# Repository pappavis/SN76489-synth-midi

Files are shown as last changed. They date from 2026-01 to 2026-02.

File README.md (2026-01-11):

Educatieve DIY USB-MIDI synthesizer gebaseerd op de SN76489 PSG,
aangestuurd via een ESP32-C2 met CircuitPython en een PCF8574
(I2C → parallel).

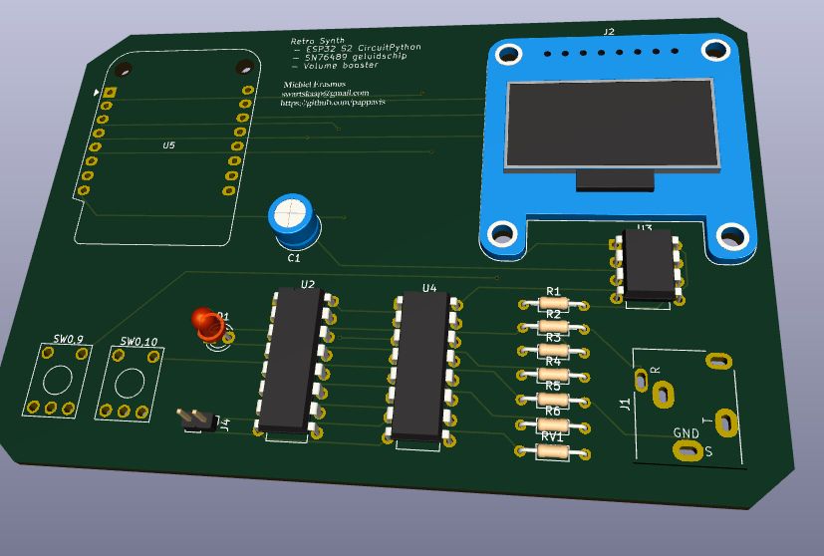
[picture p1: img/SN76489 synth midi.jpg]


# Functionele specificaties  

## Ontwerpfilosofie
- Eerst breadboard, dan PCB
- Alles meetbaar met scope en multimeter
- Geen SMD-componenten
- Focus op leerbaarheid en reproduceerbaarheid

## Signaalpad (verplicht)
ESP32-C2 (USB MIDI)
→ PCF8574
→ SN76489
→ analoge filtering
→ variabel mono volume
→ audio-versterker
→ 3.5 mm TRS koptelefoon (dual-mono)

## Projectstatus
- [x] Stap 1 – Functionele specificaties
- [ ] Stap 2 – Technische specificaties
- [ ] Stap 3 – Blokdiagram
- [ ] Stap 4 – Breadboard ontwerp
- [ ] Stap 5 – Audio-versterker evaluatie
- [ ] Stap 6 – KiCad schema & PCB
- [ ] Stap 7 – Firmware architectuur
- [ ] Stap 8 – Test & debug
- [ ] Stap 9 – Verbeteringen

➡️ Begin bij `docs/01-functional-spec.md`
sn76489-midi-synth/
├── README.md
├── docs/
│   ├── 01-functional-spec.md
│   ├── 02-technical-spec.md
│   ├── 03-block-diagram.md
│   ├── 04-breadboard-design.md
│   ├── 05-audio-options-evaluation.md
│   ├── 06-kicad-design.md
│   ├── 07-firmware-architecture.md
│   ├── 08-test-and-debug.md
│   └── 09-improvements-and-next-steps.md
├── hardware/
│   ├── breadboard/
│   └── pcb/
├── firmware/
│   ├── circuitpython/
│   └── tools/
└── media/
    ├── photos/
    └── scope-captures/

# Werk-in-uitvoering

## Functioneel schema
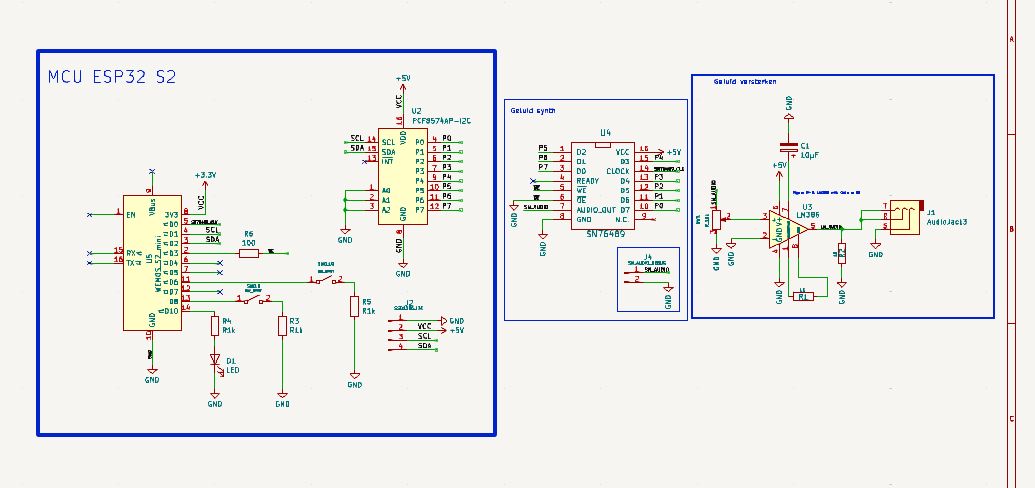
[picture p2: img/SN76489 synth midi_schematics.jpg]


## Printplaat klaar voor China-produtie
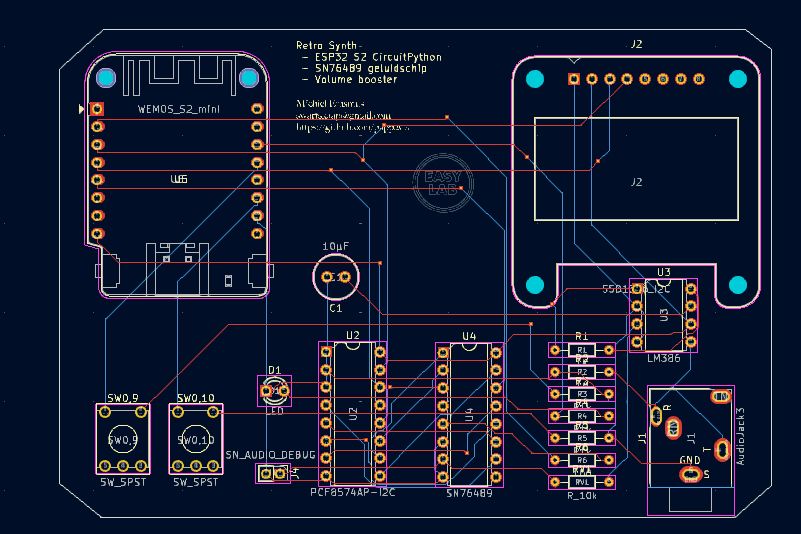
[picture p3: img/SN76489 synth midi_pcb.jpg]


# CREDITS
In een opwelling gemaakt op een koude Zaterdagmiddag.

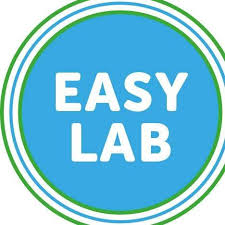
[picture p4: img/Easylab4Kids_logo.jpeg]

Michiel Erasmus

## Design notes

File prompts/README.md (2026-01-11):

9-Jan-2026. Help mij om een prompt te schrijven als hobby-elektronica-ontwikkelaar vergelijkbaar met iemand zoals Krijtskot op YouTube.

# idee
Ik wil een SN76489IC chip gebruiken met een ESP32C2 om daar een MIDI synth van te maken. De ESP32-C2 wordt door Logic Pro gezien als Midi controller.  De ESP32 vertaalt midi noten naar  Sn76489 
De ESP32 C2 midi controller "firmware" wordt ontwikkeld met CircuitPython.

# instructies
1. Genereer een  prompt die mij helpen van functionele specificaties maken, naar technische specs, naar KICAD schema ontwerp, en de juiste . Jouw output in Markdown formaat waar nodig.
2. Blijf verbeter voorstellen doen totdat ik zeg je moet stop.
3. Verwerk de instructies van deze prompt in jouw reactie.

# Informatiebronnen
1. zie mijn eigen KiCAD PCB ontwerp op https://github.com/pappavis/EasyLab-retro-synth-SN76489
2. SN76489 datasheet --> https://map.grauw.nl/resources/sound/texas_instruments_sn76489an.pdf

Blijf verbetervoorstellen doen zodat ik deze prompt kan verbeteren

toevoegen aan de voorbeeld prompt:

=====
Je bent een ervaren hobby-elektronica ontwikkelaar en educator, in de stijl van GreatScott op YouTube:
pragmatisch, technisch eerlijk, nieuwsgierig en iteratief.

## Projectcontext
Ik bouw een DIY MIDI-synth op basis van de SN76489 sound chip en een ESP32-C2.
- De ESP32-C2 draait CircuitPython
- De ESP32-C2 wordt door Logic Pro herkend als USB MIDI device
- MIDI Note On/Off, velocity en channel worden vertaald naar SN76489 register writes
 - Geluid output van de SN76489 is naar een TENSATR PCM5102 Interface I2S DAC Decoder  (https://nl.aliexpress.com/item/1005009897846559.html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)
- Doel: leerzaam, reproduceerbaar en uitbreidbaar ontwerp

## Informatiebronnen
- Bestaand KiCad project: https://github.com/pappavis/EasyLab-retro-synth-SN76489
- SN76489 datasheet: https://map.grauw.nl/resources/sound/texas_instruments_sn76489an.pdf

## Taken (voer deze in volgorde uit)
1. Formuleer functionele specificaties (gebruikersniveau)
2. Vertaal deze naar technische specificaties (signalen, timing, spanningen)
3. Ontwerp een logisch blokdiagram (tekstueel beschreven)
4. Werk toe naar een KiCad-schema:
   - voedingsontwerp
   - klokbron
   - data- en controlijnen SN76489
   - ESP32-C2 pinmapping
5. Beschrijf firmware-architectuur in CircuitPython:
   - MIDI stack
   - notenmapping
   - timingstrategie
6. Benoem risico’s, onzekerheden en meetpunten
7. Doe concrete verbetervoorstellen en stel expliciet vervolgvragen

## Extra aandachtspunten
- Ga uit van SN76489AN compatibiliteit en benoem verschillen met SN76496
- Houd rekening met write-timing (minimum pulse widths)
- Veronderstel geen interrupts in CircuitPython zonder dit expliciet te motiveren
- Beschrijf hoe je het ontwerp zou testen met een logic analyzer en scope
- Geef alternatieven als CircuitPython timing tekortschiet

## Educatieve insteek
- Leg beslissingen uit alsof dit een YouTube-episode is
- Benoem expliciet: "dit is waarom dit fout kan gaan"
- Splits het project in afleveringen / milestones
- Benoem wat je NIET doet en waarom
- Geef suggesties voor toekomstige uitbreidingen:
  - envelope generator
  - noise channel modulation
  - polyfonie via multiple SN chips

## Stijl
- Markdown waar nuttig
- Geen marketingtaal
- Leg keuzes uit alsof je ze op camera verdedigt
- Doe altijd verbetervoorstellen tot ik "stop" zeg

# Mijn Update aan jouw concept prompt .

Ik wil de SN76489 geluid output volume kunnen boosten door bijvoorbeeld de PCM5102 module  te vervangen met een LM386, de geluid output moet op kanaal links en rechts zijn. De output geluid met een variable volume naar een koptelefoon TRS-output.
Update de prompt 
# met voorstel voor alternatieven van een LM386.
# De chip ontwerp is ESP32 C2 als midicontroller --> PCF8574 I2c --> SN76489 --> variabel (mono) volume zoals potmeter --> volume booster module/breakoutboard  --> TRS output
# toevoegen aan jouw voorstel prompt.
de test en ontwerp software en apparatuur tot mijn beschikking:
 - Kicad 8.0
 - 3d printer
 - Riden RC6006 labvoeding
 - RIGOL DHO804 oscilloscoop
 - Aneng SZ02 multimeter
 - Breadbords
 - Jumper kabels
 - verschillende microcontrollers zoals Pi PICO, ESp32 S2, ESP32 C3.

 update aan de prompt.
1. Stap 1 is beginnen met een KICAD ontwerp ESP32 --> PC8574 --> SN76489 --> LM386 --> dual mono booster zoals een SAM-breakoutboard --> variabel volume beheer bijvb door een potmeter --> TRS headphone audio out jack.
2. De ontwerp heeft ook een SSD1302 I2C mini LCD voor gebruikers output.

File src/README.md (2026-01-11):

# CircuitPython Skeleton (SN76489 + PCF8574)

# Instructies
Hier is je minimale CircuitPython skeleton als ZIP (main.py + drivers + config + diagnostics):

Download sn76489_circuitpython_skeleton.zip￼

Gebruik (kort):
	1.	Unzip.
	2.	Kopieer de inhoud naar je CIRCUITPY drive.
	3.	Zet in system/config.py je PCF_ADDR en (indien nodig) PCF_STROBE_BIT.
	4.	Start met TEST_MODE = "pcf_counter" (scope op D0..D7 + strobe).
	5.	Daarna TEST_MODE = "sn_beep" (scope op strobe + audio out).

## Wat is dit?
Minimale bring-up firmware voor:
- I2C scan (MP1)
- PCF8574 data togglen (MP2)
- SN76489 byte writes + simpele beep (MP3/MP4)
- OLED status (optioneel; faalt veilig)

## Installatie (CircuitPython)
1. Flash CircuitPython op je ESP32-C2 board.
2. Kopieer de hele inhoud van deze map naar de CIRCUITPY drive.
3. Installeer (optioneel) OLED libs als je het display gebruikt:
   - adafruit_ssd1306.mpy
   - adafruit_display_text/
   - terminalio (meestal ingebouwd)

## Test modes
In `system/config.py`:
- `TEST_MODE = "pcf_counter"`  → PCF bus telt 0..255 (scope op D0..D7)
- `TEST_MODE = "sn_beep"`      → SN76489 korte beep
- `TEST_MODE = None`           → idle loop

## Belangrijk
- Dit skeleton bevat nog geen USB-MIDI parser.
- Eerst hardware brengen naar "beep" en "stabiele bus". Daarna MIDI laag toevoegen.

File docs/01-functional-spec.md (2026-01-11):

# Stap 1 – Functionele specificaties
DIY USB-MIDI PSG-synth (SN76489 + ESP32-C2)

## 1. Hoofdfunctie
Een standalone USB-MIDI synthesizer die MIDI-noten omzet naar
klassieke PSG-audio via de SN76489, met regelbare mono-audio
op een koptelefoonuitgang.

## 2. Gebruikersperspectief
### Input
- USB MIDI device
- Note On / Off
- Velocity (optioneel)
- MIDI Channel

### Output
- Direct hoorbaar geluid
- Fysieke volumeregeling
- 3.5 mm TRS koptelefoon (dual-mono)

### Feedback
- OLED-display (SSD1306/1309-klasse)
- Toon van MIDI-status en actieve voices

## 3. Synth-gedrag
- 3 toonkanalen + 1 noise-kanaal
- Monofonisch per kanaal
- Geen envelopes of modulatie

## 4. Digitale keten
USB MIDI
→ ESP32-C2 (CircuitPython)
→ PCF8574
→ SN76489
→ analoge audio

## 5. Audio-pad
SN76489
→ filtering
→ volumepotmeter
→ audio-versterker
→ koptelefoon

## 6. Buiten scope
Geen presets, geen CC’s, geen stereo, geen batterij,
geen SMD, geen PCB-optimalisatie.

## 7. Meetbaarheid
Alles moet testbaar zijn op breadboard met scope,
multimeter en serial debug.

## 8. Succescriteria
Heldere scope, reproduceerbaar ontwerp,
en een solide basis voor stap 2.

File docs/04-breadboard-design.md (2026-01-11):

- Dit punt ligt **bij de voeding / USB-entry**
- Audio-ground mag **nooit** via ESP32 of I2C teruglopen

---

## 3. Digitale sectie – wiring details

### 3.1 ESP32-C2

- Voeding: via USB
- Gebruik alleen:
  - SDA
  - SCL
  - 1–2 GPIO’s voor SN76489 control (via PCF)
- Geen lange jumper wires (>10 cm = fout)

### 3.2 I2C-bus

- SDA + SCL getwist of parallel naast elkaar
- Pull-ups: 4.7–10 kΩ naar **+5 V_DIG**
- Devices:
  - PCF8574
  - OLED

Testregel:
- Eerst I2C scan → dan pas SN76489 aansluiten

---

## 4. PCF8574 → SN76489 wiring

### 4.1 Parallel data

- PCF8574 D0–D7 → SN76489 data bus
- Draden:
  - zo kort mogelijk
  - naast elkaar (geen kruisende audio)

### 4.2 Control lines

- WE / strobe apart en zichtbaar routen
- Label op breadboard (tape!) aanbevolen

Meetpunt MP2 / MP3:
- Je moet hier met de scope **duidelijk pulsen** zien

---

## 5. Audio sectie – wiring details (Optie B leidend)

### 5.1 SN76489 audio out

- AC-koppeling **direct bij SN76489**
- Daarna pas draad richting potmeter

Fout:
- Eerst lange draad → dan C_in (pikt rommel op)

### 5.2 Potmeter

- Mono, 10–50 kΩ log
- Aansluiting:
  - boven: audio in
  - midden: wiper → versterker
  - onder: GND_AUD

### 5.3 Opamp-versterker (Optie B)

- Zo dicht mogelijk opgebouwd
- Decoupling:
  - 100 nF direct tussen VCC en GND
  - Cref (47–100 µF) bij Vref-node
- Vref-buffer fysiek dichtbij opamp

### 5.4 TRS jack

- Tip = L
- Ring = R
- Sleeve = GND_AUD
- Serie-R en C_out **vlakbij jack**

---

## 6. Absolute breadboard no-go’s

- ❌ Audio en I2C draden door elkaar
- ❌ GND-lussen
- ❌ Lange ongefilterde audio-ingang
- ❌ Geen decoupling “omdat het ook zonder werkt”
- ❌ Alles op één rail “want dat is makkelijker”

---

## 7. Bouwvolgorde (afdwingend)

### Fase 1 – Digitaal leven
1. ESP32 → USB
2. USB MIDI zichtbaar
3. OLED werkt
4. I2C scan ziet PCF8574

### Fase 2 – Parallel output
5. PCF8574 outputs togglen (LED of scope)
6. Strobe-lijn zichtbaar op scope

### Fase 3 – PSG
7. SN76489 aangesloten
8. Eenvoudige “beep” via vaste waarde
9. Audio zichtbaar op scope (MP4)

### Fase 4 – Audio pad
10. Potmeter werkt (MP5)
11. Opamp versterkt correct
12. Koptelefoon-uitgang schoon (MP6)

**Niet doorbouwen als een eerdere fase niet klopt.**

---

## 8. Meetplan (samenvatting MP0–MP6)

| Meetpunt | Wat | Verwachting |
|---|-----|---|
| MP0 | USB MIDI | Device zichtbaar |
| MP1 | I2C scan | OLED + PCF ACK |
| MP2 | PCF data | Bits togglen |
| MP3 | Strobe | Duidelijke pulses |
| MP4 | PSG audio | Klein AC signaal |
| MP5 | Potmeter | Variërende amplitude |
| MP6 | Jack L/R | Identiek signaal |

---

## 9. Succescriteria Stap 4

Stap 4 is geslaagd als:
- Breadboard visueel logisch is
- Elk blok apart meetbaar is
- Ruis en fouten **herleidbaar** zijn
- Je zonder schema kunt uitleggen wat waar gebeurt

---

## Volgende stap
**Stap 5 – Audio-opties evaluatie (A/B/C)**  
→ Optie A en B zijn nu uitgewerkt  
→ Optie C kan nog toegevoegd worden  
→ Daarna: definitieve keuze voor PCB

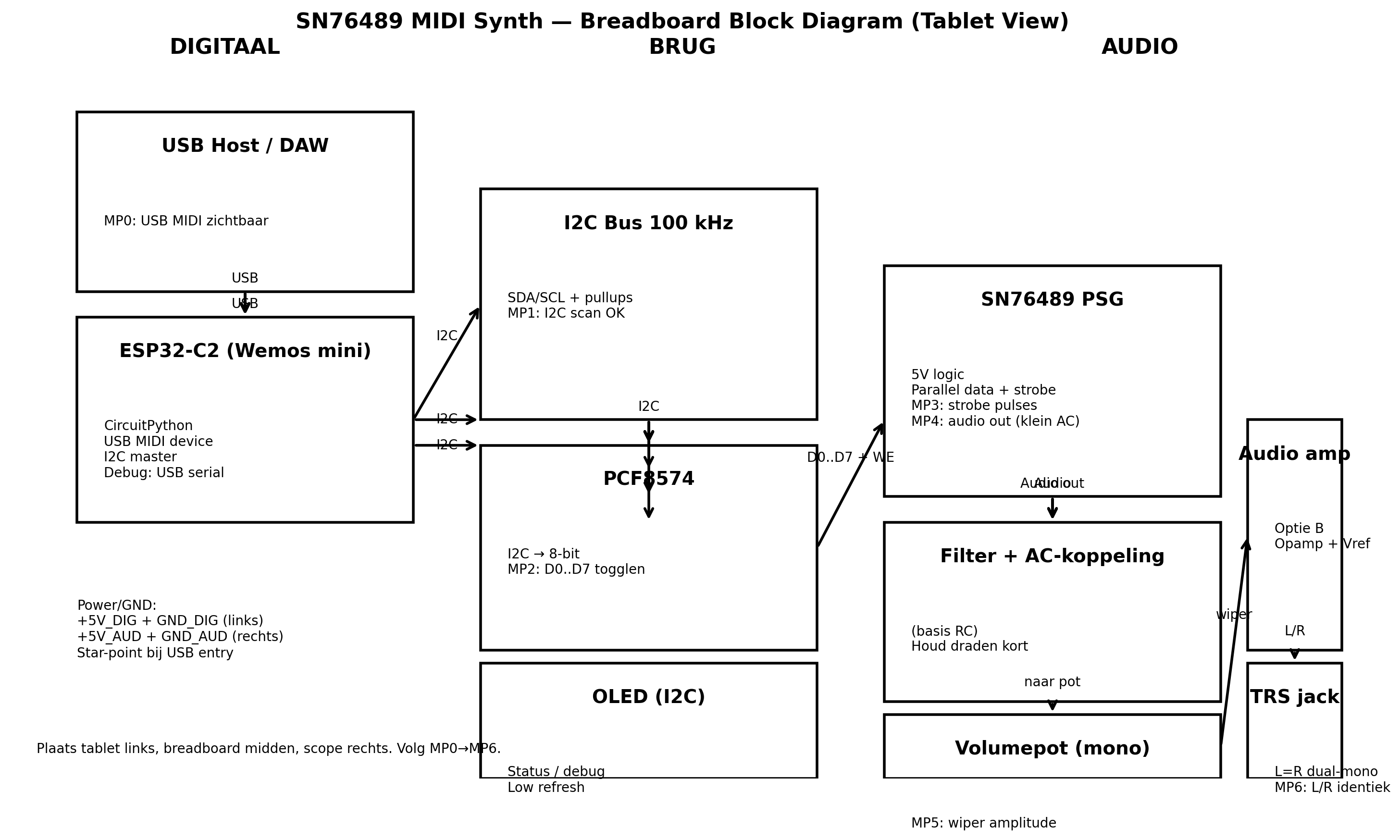
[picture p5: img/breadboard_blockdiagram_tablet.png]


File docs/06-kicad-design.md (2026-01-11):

# Stap 6 – KiCad schema & PCB-aanpak
DIY USB-MIDI PSG-synth (SN76489 + ESP32-C2)

Doel van deze stap:
- Breadboard-ontwerp **1-op-1 vertalen** naar schema
- Geen nieuwe ideeën introduceren
- PCB zo ontwerpen dat fouten **moeilijk** worden

Ontwerpregel (hard):
> Wat niet bewezen is op breadboard, mag niet op de PCB.

---

## 1. Scope van de PCB (V1)

### Wat komt **wel** op de PCB
- ESP32-C2 (Wemos mini footprint of headers)
- PCF8574 (DIP)
- SN76489 (DIP)
- I2C OLED header
- Audio-versterker **Optie B (opamp-based)**
- Potmeter (board-mount of via header)
- 3.5 mm TRS jack
- Alle ontkoppeling en passives (THT)

### Wat komt **niet** op de PCB
- LM386 (blijft optioneel / extern)
- Batterij, laadcircuits
- Extra knoppen / encoders
- Stereo uitbreidingen
- “Handige extra headers” zonder bewezen nut

---

## 2. Schema-opbouw in KiCad (afdwingende volgorde)

### 2.1 Schema hiërarchie (aanrader)

Gebruik **hiërarchische sheets**:
Top.sch
├── Power.sch
├── MCU_USB.sch
├── I2C_Bus.sch
├── PSG_SN76489.sch
├── Audio_Amplifier_Opamp.sch
└── IO_Audio.sch

Waarom:
- Elk blok = 1 mentale eenheid
- Reviewbaar
- Makkelijk debuggen bij fouten

---

## 3. Power & ground schema (Power.sch)

### Netnamen (verplicht)
- +5V_DIG
- GND_DIG
- +5V_AUD
- GND_AUD

### Eisen
- +5V_DIG en +5V_AUD **pas samen** bij USB-entry
- GND_DIG en GND_AUD **pas samen** bij star-point
- Elk IC:
  - 100 nF keramisch direct bij VCC–GND
- Extra bulk:
  - 10–47 µF per sectie

---

## 4. MCU & USB (MCU_USB.sch)

### ESP32-C2 (Wemos mini)
- USB direct naar connector
- Geen extra ESD/filters in V1
- Headers voor:
  - SDA
  - SCL
  - debug GPIO (optioneel)

### Eisen
- Geen 5 V op GPIO’s
- I2C op vaste pins documenteren in schema-notes

---

## 5. I2C bus (I2C_Bus.sch)

### Componenten
- PCF8574
- OLED header

### Eisen
- Pull-ups: 4.7–10 kΩ naar +5V_DIG
- Netlabels:
  - SDA
  - SCL
- Adressen als tekst in schema (comment)

---

## 6. PSG-sectie (PSG_SN76489.sch)

### SN76489
- VCC = +5V_DIG
- Decoupling:
  - 100 nF direct
  - 10 µF bulk dichtbij

### Parallel bus
- D0..D7 expliciet gelabeld
- Control-lijn (WE / strobe) duidelijk benoemd

### Audio-out
- AC-koppeling **direct bij IC**
- Netlabel: `PSG_AUDIO_RAW`

---

## 7. Audio amplifier (Audio_Amplifier_Opamp.sch)

### Gebaseerd op Optie B
- Opamp: LM358 (DIP)
- Virtuele ground:
  - R-divider + buffer
  - Netlabel: `VREF_AUD`

### Netnamen
- `AUDIO_IN`
- `AUDIO_POST_POT`
- `AUDIO_L`
- `AUDIO_R`

### Eisen
- DC-blokkering vóór TRS jack
- Serie-R per kanaal

---

## 8. IO & Audio jack (IO_Audio.sch)

### Potmeter
- Mono, log
- Board-mount of header → kies één

### TRS jack
- Tip = AUDIO_L
- Ring = AUDIO_R
- Sleeve = GND_AUD

### Extra
- Bleeder resistors naar GND_AUD

---

## 9. PCB-layout strategie (belangrijker dan schema)

### 9.1 Plaatsing (volg breadboard-zones)
[ USB + MCU ] [ I2C + PCF ] [ SN76489 ] [ AUDIO ]

- Links → rechts
- Geen kruisende signaalpaden

### 9.2 Grounding
- Volledig ground plane
- Split via netnames (DIG/AUD)
- Star-point bij USB-entry

### 9.3 Routing-regels
- Audio sporen kort, breed, weg van I2C
- Geen digitale sporen onder opamp-inputs
- Decoupling caps <5 mm van IC-pins

---

## 10. Footprints & THT-keuzes

- Alles **through-hole**
- DIP-8 / DIP-16 waar mogelijk
- Headers i.p.v. direct solderen bij twijfel
- Potmeter en jack: mechanisch robuust

---

## 11. ERC / DRC checklist

Voor productie:
- [ ] ERC = 0 errors
- [ ] DRC = 0 errors
- [ ] Alle netlabels kloppen
- [ ] GND_DIG ≠ GND_AUD behalve star-point
- [ ] Audio nets niet per ongeluk op DIG-ground

---

## 12. Succescriteria Stap 6

Stap 6 is geslaagd als:
- Schema exact overeenkomt met breadboard
- PCB logisch “leesbaar” is zonder schema
- Audio- en digitale secties fysiek gescheiden zijn
- Geen “ik dacht dat het wel handig was”-beslissingen

---

## Volgende stap
**Stap 7 – Firmware-architectuur (CircuitPython)**

- USB MIDI handling
- Voice-allocatie
- SN76489 write-sequence
- Testmodes per meetpunt (MP0–MP6)

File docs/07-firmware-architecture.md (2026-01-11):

# Stap 7 – Firmware-architectuur (CircuitPython)
DIY USB-MIDI PSG-synth (SN76489 + ESP32-C2)

Doel:
- Firmware opdelen in **begrijpelijke, testbare lagen**
- Hardware abstraheren (I2C, PCF8574, SN76489)
- Debug en test mogelijk maken per meetpunt (MP0–MP6)

Ontwerpregel:
> Firmware mag nooit “slim” zijn waar hardware dat al afdwingt.

---

## 1. Architectuur-overzicht

### Hoofdstructuur
main.py
│
├── midi/
│   ├── usb_midi.py
│   └── note_mapper.py
│
├── drivers/
│   ├── pcf8574.py
│   ├── sn76489.py
│   └── oled_status.py
│
├── audio/
│   └── voice_allocator.py
│
├── system/
│   ├── config.py
│   └── diagnostics.py
│
└── test_modes.py

Elke map = één verantwoordelijkheid.

---

## 2. main.py (orchestratie)

### Verantwoordelijkheden
- Initialisatie van alle subsystemen
- Hoofdloop
- Foutafhandeling (fail-safe gedrag)

### Gedrag
- Start altijd op, ook zonder MIDI
- OLED toont status (“BOOT”, “MIDI OK”, “NO MIDI”)
- Testmodus kan geforceerd worden (bijv. via flag in config)

Pseudo-flow:
boot →
init I2C →
init PCF →
init SN76489 →
init OLED →
init MIDI →
enter main loop

---

## 3. USB MIDI laag (`midi/usb_midi.py`)

### Taken
- USB MIDI device openen
- MIDI messages parsen
- Alleen relevante events doorgeven:
  - Note On
  - Note Off
  - (optioneel) velocity

### Eisen
- Niet blokkeren
- Geen audio-logica hier
- “Dode” MIDI events negeren

Output (event-object):
{
type: NOTE_ON / NOTE_OFF,
note: 0–127,
velocity: 0–127,
channel: 0–15
}

Meetpunt:
- **MP0**: MIDI events zichtbaar via debug print

---

## 4. Voice-mapping & allocatie (`audio/voice_allocator.py`)

### Taken
- MIDI note → SN76489 voice
- Round-robin allocatie over 3 toonkanalen
- Noise-kanaal apart behandelen

### Simpele V1-logica
- 3 tone voices: CH0, CH1, CH2
- Nieuwe Note On:
  - wijs eerst vrije voice toe
  - anders: round-robin overschrijven
- Note Off:
  - mute voice als noot matcht

### Output
- Abstract “voice command”, geen hardware-kennis:

set_voice(channel, frequency, volume)
mute_voice(channel)

---

## 5. SN76489 driver (`drivers/sn76489.py`)

### Taken
- Vertaal abstracte voice-commando’s naar PSG writes
- Bereken frequentie → registerwaarden
- Volume mapping (optioneel via velocity)

### Interface
- `write_byte(value)`
- `set_tone(channel, freq)`
- `set_volume(channel, level)`
- `mute(channel)`

### Eisen
- Geen MIDI-kennis
- Geen I2C-kennis
- Alleen “ik wil deze byte schrijven”

Meetpunt:
- **MP3**: strobe pulses zichtbaar
- **MP4**: audio op output

---

## 6. PCF8574 driver (`drivers/pcf8574.py`)

### Taken
- I2C-communicatie met PCF8574
- 8-bit parallel data aanbieden
- Control-lijnen beheren (WE/strobe)

### Interface
- `set_data(byte)`
- `pulse_write()`
- `write(byte)` (combinatie van bovenstaand)

### Timing
- Simpel, conservatief:
  - set data
  - korte delay (µs–ms orde)
  - pulse strobe
  - delay

Meetpunt:
- **MP2**: D0–D7 togglen zichtbaar

---

## 7. OLED status (`drivers/oled_status.py`)

### Taken
- Minimale statusweergave
- Geen grafische fratsen

### Weergavevoorbeelden
- BOOT
- MIDI OK
- MIDI CH: 1
- ACTIVE VOICES: 2

### Eisen
- Updates max ~10 Hz
- OLED mag nooit MIDI of audio blokkeren

Meetpunt:
- **MP1**: OLED reageert op statuswijziging

---

## 8. Configuratie (`system/config.py`)

### Bevat
- I2C-adressen
- MIDI-kanaal-instellingen
- Testmode flags
- Debug verbosity

Voorbeeld:

I2C_FREQ = 100_000
PCF_ADDR = 0x20
OLED_ADDR = 0x3C
DEBUG = True

---

## 9. Diagnostics & testmodes (`system/diagnostics.py`, `test_modes.py`)

### Doel
- Hardware testen zonder MIDI
- Meetpunten afdwingen

### Testmodes (V1)
- Test 1: PCF8574 teller (0x00 → 0xFF)
- Test 2: SN76489 vaste toon (“beep”)
- Test 3: Volume sweep
- Test 4: OLED status cycling

Meetpunten:
- MP2 → MP6 zonder DAW of MIDI-controller

---

## 10. Fail-safe gedrag (belangrijk)

- Geen MIDI → geen crash
- OLED fout → audio blijft werken
- PCF fout → duidelijke debugmelding
- Onverwachte fout → systeem blijft in loop

Geen watchdogs of RTOS in V1.

---

## 11. Succescriteria Stap 7

Stap 7 is geslaagd als:
- Elke laag afzonderlijk te testen is
- Hardware-drivers geen MIDI-logica bevatten
- MIDI-code geen hardware-details kent
- Testmodes MP0–MP6 onafhankelijk afdwingbaar zijn

---

## Volgende stap
**Stap 8 – Test- en debug-strategie**

- Concrete meetprocedures
- Verwachte golfvormen
- “Als X niet werkt, check Y”

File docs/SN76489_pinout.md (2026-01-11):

# SN76489 IC Pinout (DIP-16)

Nette, breadboard- en KiCad-vriendelijke ASCII-weergave van de **klassieke TI SN76489**.

# Pinout
---

## Pin-functie overzicht (praktisch)

### Data bus
- **D0–D7 (pins 1–8)**  
  8-bit parallel data-bus  
  → afkomstig van **PCF8574**

---

### Control-signalen
- **WE (pin 9)** – *Write Enable*  
  - Korte puls per register-write  
  - Polariteit afhankelijk van wiring  
  - **Meest kritische signaal**

- **CLK (pin 10)** – *Clock input*  
  - Sommige chips/modules: **interne clock**  
  - Andere: **externe clock vereist** (typisch ±3.58 MHz)

- **CE (pin 11)** – *Chip Enable*  
  - Meestal **actief LOW**  
  - Vaak permanent LOW vastgelegd in V1

---

### Audio & voeding
- **AUDIO OUT (pin 12)**  
  - Mono analoog audio  
  - **Altijd AC-koppelen direct bij de chip**

- **+5V (pin 13)**  
  - Digitale voeding  
  - Verplicht:
    - 100 nF keramisch
    - 10 µF elco  
    (zo dicht mogelijk bij de pin)

- **GND (pin 14)**  
  - Digitale ground

---

### Overig
- **NC (pins 15–16)**  
  - Niet aangesloten

---

## Ontwerp-waarschuwing (belangrijk)

> **80 % van “geen geluid” bugs bij de SN76489 zit in:**
>
> - verkeerde **WE-polariteit**
> - ontbrekende of verkeerde **CLK**
> - **CE** per ongeluk niet actief

Controleer deze drie altijd **eerst met de scope** voordat je audio of firmware verdenkt.

---

# ASCII-schema — PCF8574 → SN76489 wiring

Dit document toont **exact** hoe je de **PCF8574 (I²C → parallel expander)** koppelt aan de  
**SN76489 PSG**, geschikt voor **breadboard**, **KiCad** en **firmware-afstemming**.

---

## 1. Overzicht (conceptueel)

ESP32 (I2C)
│
│  SDA / SCL
▼
┌───────────┐        8-bit parallel + strobe        ┌────────────┐
│ PCF8574   │ ───────────────────────────────────▶ │ SN76489    │
│ I2C exp.  │                                      │ PSG        │
└───────────┘                                      └────────────┘

---

## 2. Bit-voor-bit mapping (aanbevolen)

### PCF8574 → SN76489 data- en control-lijnen
PCF8574                          SN76489 (DIP-16)
────────                          ───────────────

P0  ───────────────────────────▶  D0   (pin 1)
P1  ───────────────────────────▶  D1   (pin 2)
P2  ───────────────────────────▶  D2   (pin 3)
P3  ───────────────────────────▶  D3   (pin 4)
P4  ───────────────────────────▶  D4   (pin 5)
P5  ───────────────────────────▶  D5   (pin 6)
P6  ───────────────────────────▶  D6   (pin 7)
P7  ───────────────────────────▶  D7   (pin 8)

WE_STROBE (PCF bit) ───────────▶  WE   (pin 9)
> 💡 **Aanbevolen keuze:** gebruik **PCF8574 P7 als WE**  
> → eenvoudig te maskeren en pulsen in firmware.

---

## 3. Control- en vaste pinnen (V1-afspraak)

SN76489 pin 11 (CE)   ─────────▶  GND_DIG   (altijd enabled)
SN76489 pin 10 (CLK)  ─────────▶  externe clock of module-clock
SN76489 pin 13 (+5V)  ─────────▶  +5V_DIG
SN76489 pin 14 (GND)  ─────────▶  GND_DIG

- **CE**: vast aan GND (geen software-control in V1)
- **CLK**: afhankelijk van chip/module (interne of externe clock)

---

## 4. Volledig ASCII-overzicht (breadboard-vriendelijk)
PCF8574                         SN76489
┌──────────┐                   ┌─────────────────┐
│ P0   ────┼──────────────────▶│ D0          16 │ NC
│ P1   ────┼──────────────────▶│ D1          15 │ NC
│ P2   ────┼──────────────────▶│ D2          14 │ GND
│ P3   ────┼──────────────────▶│ D3          13 │ +5V
│ P4   ────┼──────────────────▶│ D4          12 │ AUDIO OUT
│ P5   ────┼──────────────────▶│ D5          11 │ CE ──┐
│ P6   ────┼──────────────────▶│ D6          10 │ CLK  │
│ P7   ────┼─────┐             │ D7           9 │ WE ◀─┘
└──────────┘     │             └─────────────────┘
└── WE_STROBE

---

## 5. Firmware-implicatie (essentieel)

### Write-sequence (PCF8574 → SN76489)

```python
pcf.set_data(byte)     # zet D0..D7
pcf.pulse_strobe()    # pulse WE

Stappen:
	1.	Data-byte op P0–P7
	2.	Korte settle-tijd
	3.	WE-puls (actief LOW of HIGH)
	4.	Write voltooid

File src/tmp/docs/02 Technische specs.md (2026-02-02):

# Tegniese Spesifikasie (TS) v1.5.1  
## SN76489 Emulator v0.06 – Volledige Tegniese Kontrak (MacOS, Python) — Tightened

Datum: 2 Februarie 2026  
Gebaseer op: Funksionele Spesifikasie (FS) v1.6 (goedgekeur)  
Target platform: MacOS 26.2  
Python: 3.12  
Artefak: Eén Python-bestand (`sn76489_emulator.py`)  
Status: Tegniese kontrak – volledig, geen implementasie-kode

---

## 0. Doel en Reikwydte van TS v1.5.1

TS v1.5.1 beskryf die volledige tegniese ontwerp van die SN76489 emulator/engine soos dit bestaan ná v0.05 en met die toevoeging van VGM playback (v0.06), met kontrak-verstrakking sodat geen komponent (mens of Copilot) hoef te raai nie.

Hierdie dokument:
- vervang nie vorige TS’e nie
- inkorporeer TS v1.4 volledig
- inkorporeer TS v1.5 volledig
- verstrak (tighten) spesifiek:
  - debug parameter echo (format + inhoud)
  - CLI konflik-matriks (mutual exclusivity + invalid kombinasies)
  - VGM parser subset (presiese command bytes)
  - VGM wait/timing model (presies)
  - `--vgm-list` output kontrak (presies)
  - error message format (presies, copy/paste-baar)
  - commit style (ASCII, code block)

TS v1.5.1 is die tegniese kontrak vir v0.06 implementasie.

---

## 1. Hoëvlak Argitektuur

Die emulator bestaan logies uit:

1. CLI / Runtime mode selector  
2. Audio engine (stream/block renderer)  
3. SN76489 chip core(s) (1–128 chips)  
4. Voice allocation + envelope engine (polyfonie per chip)  
5. MIDI input layer (CoreMIDI via python-rtmidi)  
6. VGM playback layer (file parser + scheduler)  
7. Debug & inspectie layer (dump/counters/debug/echo)

Alles bly binne één Python-bestand, maar met streng skeiding van verantwoordelikhede.

---

## 2. SN76489 Core Emulasie

### 2.1 Chip Model

Elke SN76489-chip implementeer:
- 3 tone-kanale
- 1 noise-kanaal
- 8 interne registers
- latch/data write gedrag

Registers (logiese map):
- Tone 0 period (10-bit)
- Tone 1 period (10-bit)
- Tone 2 period (10-bit)
- Noise control
- Volume registers (4-bit) per kanaal

Volume betekenis:
- 0 = maksimum volume
- 15 = mute

Alle klank ontstaan uitsluitlik deur register writes.

### 2.2 Noise Generator

- White noise
- Periodic noise
- Rate seleksies:
  - div16
  - div32
  - div64
  - tone2-linked
- LFSR implementasie
- Opsionele seed (`--noise-seed`) vir determinisme

---

## 3. Audio Rendering & Timing

### 3.1 Sample Rate
- Konfigureerbaar
- Default: 44100 Hz

### 3.2 Block Rendering
- Audio word gegenereer in blokke (`--block-frames`)
- Geen sample-accurate scheduling vereis nie
- Block-accurate timing is voldoende

---

## 4. Multi-chip Argitektuur

- 1 tot 128 SN76489 chips
- Elke chip:
  - eie registers
  - eie voices
  - eie envelopes
  - eie counters

Mixer:
- Lineêr O(N)
- Geen gedeelde mutable state
- Per-chip gain (opsioneel)
- Global master gain (verpligtend)

---

## 5. Stereo Routing

- Routing opsies:
  - left
  - right
  - both (dual-mono)
- Routing geld per run (global) of per chip (implementasie-keuse)
- Normatief vir v0.06: global routing via `--pan {left|right|both}`

---

## 6. Voice Allocation (Polyfonie)

Elke chip het presies 3 stemme:
- voice 0 → tone0
- voice 1 → tone1
- voice 2 → tone2

Stem-state:
- IDLE
- ATTACK
- DECAY
- SUSTAIN
- RELEASE

### 6.1 Allocation Algoritme (normatief)

By MIDI NOTE_ON:
1. Soek eerste vrye stem (tone0 → tone1 → tone2)
2. Indien geen stem vry is nie:
   - NOTE_ON word geïgnoreer
   - Geen voice stealing in v0.06

---

## 7. Envelope Engine (ADSR-lite)

### 7.1 Beginsels
- Envelopes word slegs via volume register writes geïmplementeer
- Geen DSP amplitude envelopes
- 4-bit volume domein

### 7.2 Parameters (CLI)
- `--attack-ms`
- `--decay-ms`
- `--sustain-vol` (0–15)
- `--release-ms`

### 7.3 Timing Model
- Envelope stappe word block-accurate geëvalueer
- Elke volume verandering = register write
- Afronding is aanvaarbaar

---

## 8. Pitch Bend

- MIDI Pitch Bend (14-bit)
- Middelpunt = 8192
- Range: ±2 semitone (vast vir v0.06)
- Pitch bend beïnvloed slegs aktiewe stemme
- Geen vibrato / LFO

---

## 9. Runtime Modes / CLI (VOLLEDIG)

### 9.1 Test Modes
- `--test beep`
- `--test noise`
- `--test sequence`
- `--test chords`
- `--test sweep`

Elke test:
- Moet parameters echo (sien §10)
- Moet hoorbare klank lewer
- Moet stabiel wees
- Moet skoon stop

### 9.2 Debug / Inspectie
- `--dump-regs`
- `--counters`
- `--debug` (rate-limited)

Nota: `--noise-mode` en `--noise-rate` en `--noise-seed` bestaan reeds vir tests en moet in RUN CONFIG ge-echo word (sien §10).

---

## 10. Debug Output Kontrak (TIGHTENED)

### 10.1 Parameter Echo – presiese format (verpligtend)

Wanneer die program in een van hierdie modes run:
- `--test <mode>`
- `--midi-in`
- `--vgm-path <file>`
- `--vgm-list`

MOET die program ’n konsekwente, multi-line “RUN CONFIG” blok print voor playback begin.

#### 10.1.1 RUN CONFIG blok – presiese vorm

Eerste reël:
- `RUN CONFIG:`

Daarna presies hierdie sleutels (in hierdie orde), met `=`:

1. `mode=<test|midi|vgm|vgm_list>`
2. `test=<beep|noise|sequence|chords|sweep|none>`
3. `sample_rate=<int>`
4. `block_frames=<int>`
5. `chips=<int>`
6. `pan=<left|right|both>`
7. `master_gain=<float>`
8. `attack_ms=<float>`
9. `decay_ms=<float>`
10. `sustain_vol=<int>`
11. `release_ms=<float>`
12. `noise_mode=<white|periodic>`
13. `noise_rate=<div16|div32|div64|tone2>`
14. `noise_seed=<0x....>`
15. `midi_in=<0|1>`
16. `midi_port=<string|auto|none>`
17. `vgm_path=<string|none>`
18. `vgm_base_dir=<string|none>`
19. `vgm_loop=<0|1>`
20. `vgm_speed=<float>`
21. `dump_regs=<0|1>`
22. `counters=<0|1>`
23. `debug=<0|1>`

#### 10.1.2 Voorbeeld (test)

```text
RUN CONFIG:
mode=test
test=chords
sample_rate=44100
block_frames=512
chips=1
pan=both
master_gain=0.25
attack_ms=5.0
decay_ms=60.0
sustain_vol=8
release_ms=180.0
noise_mode=white
noise_rate=div32
noise_seed=0x4000
midi_in=0
midi_port=none
vgm_path=none
vgm_base_dir=none
vgm_loop=0
vgm_speed=1.0
dump_regs=1
counters=1
debug=0

10.2 --dump-regs kontrak
	•	Golden-friendly:
	•	stabiele sleutelorde
	•	geen timestamps
	•	Moet minstens bevat:
	•	chip index
	•	latched register
	•	registers R0..R7
	•	derived tone freqs
	•	noise mode/rate/seed
	•	voice allocation state per stem
	•	envelope phase per stem (state)

10.3 --counters kontrak
	•	Per chip:
	•	writes_total, latch, data
	•	renders, frames
	•	Totale:
	•	midi_events_total, note_on_total, note_off_total, pitch_bend_events
	•	voices_used_total, note_ignored_no_voice
	•	env_steps_total
	•	VGM totale (sien §14 en §17)

10.4 --debug kontrak (rate-limited)
	•	Mens-leesbare trace
	•	Geen onbounded spam
	•	Normatief:
	•	maksimum 20 debug lines per sekonde (soft limit) of “print elke N events”
	•	Mag toon:
	•	NOTE_ON/OFF
	•	stem-toewysing
	•	envelope transitions (opsioneel)
	•	VGM write + wait (opsioneel)

⸻

11. MIDI Input (VOLLEDIG)

11.1 MIDI Bron
	•	CoreMIDI (MacOS)
	•	Realtime MIDI input (python-rtmidi)

11.2 MIDI Mapping
	•	MIDI channel → chip mapping
	•	Default:
	•	channel 1 → chip 0
	•	channel 2 → chip 1
	•	ens.
	•	Indien --chips < N kleiner is as nodige channels:
	•	mapping wraps modulo chips (channel→(channel-1)%chips)

11.3 Ondersteunde Events
	•	Note On
	•	Note Off
	•	Velocity → volume mapping (4-bit)
	•	Pitch Bend (14-bit)
	•	Opsioneel: CC64 sustain

11.4 MIDI CLI
	•	--midi-list:
	•	print alle input ports
	•	exit 0
	•	--midi-in:
	•	open port “auto” (port 0) as --midi-port nie gegee is nie
	•	run until Ctrl+C
	•	--midi-port <name_substring>:
	•	kies eerste port wat substring match (case-insensitive)
	•	hard fail as niks match nie

⸻

12. CLI Konflik-Matriks (TIGHTENED)

12.1 Eksklusiewe modes (hard fail)

Die volgende kombinasies is ongeldig en MOET exit met fout:
	1.	--midi-in saam met --vgm-path
	2.	--midi-in saam met --test <mode>
	3.	--vgm-path saam met --test <mode>

12.2 Konsekwente foutboodskap

Normatief error prefix:
	•	ERROR:

Voorbeelde:
	•	ERROR: Choose either --midi-in OR --vgm-path (mutually exclusive).
	•	ERROR: Choose either --test OR --vgm-path (mutually exclusive).
	•	ERROR: Choose either --test OR --midi-in (mutually exclusive).

Normatief: exit code 2.

⸻

13. VGM Playback (NUUT in v0.06)

13.1 CLI Flags (VOLLEDIG)
	•	--vgm-path <file>
	•	--vgm-base-dir <path>
	•	--vgm-loop
	•	--vgm-speed <factor>
	•	--vgm-list

13.2 --vgm-base-dir default
	•	Indien nie gegee nie: gebruik app-config constant
	•	App-config default (FS v1.6):
	•	/Volumes/data1/Yandex.Disk.localized/michiele/Arduino/PCB Ontwerp/KiCAD/github/SN76489-synth-midi/src/tmp/src/

13.3 --vgm-list output kontrak (TIGHTENED)

Wanneer --vgm-list run:
	•	Print RUN CONFIG blok (mode=vgm_list)
	•	Print daarna:
	•	VGM LIST: <base_dir>
	•	dan elke file op eie lyn

Output format per lyn:
	•	<filename> (net file name, geen absolute path)
	•	sorteer alfabeties (case-insensitive)

Voorbeeld:
VGM LIST: /path/to/dir
01_intro.vgm
02_level1.vgm
boss_theme.vgm

Opsioneel interne datastruktuur:
	•	vgm_index: Dict[str, str]
	•	key = filename
	•	value = absolute path

13.4 --vgm-path gedrag
	•	Indien file nie bestaan nie:
	•	ERROR: VGM file not found: <path>
	•	exit code 2
	•	Indien file bestaan:
	•	start playback onmiddellik
	•	Normatief: VGM writes gaan na chip 0 (sien §16)

13.5 --vgm-loop gedrag
	•	As --vgm-loop teenwoordig:
	•	wanneer end-of-data bereik word:
	•	loop terug na command stream start
	•	increment vgm_loops_total
	•	As absent:
	•	stop playback skoon by end-of-data

13.6 --vgm-speed gedrag
	•	Float > 0 (hard fail anders)
	•	Default: 1.0
	•	Aangewend op wait/delay tyd:
	•	wait_samples_effective = round(wait_samples / vgm_speed)
	•	minimum 1 sample vir nonzero waits

⸻

14. VGM Parser Subset (TIGHTENED)

14.1 Header handling

Minimum:
	•	Validate magic string: b'Vgm '
	•	Read data offset:
	•	if data offset field = 0, default to 0x40
	•	else: data_start = 0x34 + data_offset
	•	Ignore onbekende header fields, maar moenie crash nie

14.2 Command bytes (normatief vir v0.06)

v0.06 ondersteun presies hierdie command types:
	1.	PSG write:
	•	0x50 <dd>
	2.	Wait n samples:
	•	0x61 <nn> <nn> (little endian 16-bit)
	3.	Wait 735:
	•	0x62
	4.	Wait 882:
	•	0x63
	5.	Short wait:
	•	0x70..0x7F => (cmd & 0x0F) + 1 samples
	6.	End:
	•	0x66

Alles anders:
	•	hard fail (sien §14.4)

14.3 Wait samples basis
	•	VGM wait commands is in “samples @ 44100Hz basis”
	•	Implementasie moet waits interpreteer vir engine sample_rate

Normatief:
	•	As engine sample_rate != 44100:
	•	wait_samples_engine = round(wait_samples_vgm * (engine_sr / 44100.0))
	•	Daarna apply --vgm-speed:
	•	wait_samples_effective = round(wait_samples_engine / vgm_speed)

Minimum:
	•	clamp minimum 1 sample vir nonzero waits

14.4 Unknown command error format (TIGHTENED)

As onbekende command byte gevind word:
	•	Print:
	•	ERROR: Unsupported VGM command 0xXX at offset 0xYYYYYYYY
	•	Exit code 2

Offset = file position in hex, 0-based.

⸻

15. Timing Model (VGM Scheduling)

15.1 Playback loop

Normatief:
	1.	read cmd byte
	2.	if PSG write: apply SN write onmiddellik
	3.	if wait: render audio vir wait_samples_effective in blocks
	4.	if end:
	•	if loop: seek to data_start, loops++
	•	else: stop playback

15.2 Ctrl+C gedrag

In loop playback moet Ctrl+C:
	•	stop audio stream
	•	print final counters/dump (as flags set)
	•	exit clean (exit code 0)

⸻

16. Routing + Multi-chip gedrag tydens VGM

Normatief v0.06:
	•	VGM PSG writes (0x50 dd) gaan na chip 0 se SN write()
	•	--chips > 1:
	•	chips 1..N bestaan
	•	hulle kry geen VGM writes
	•	implementasie mag hulle default mute (volume 15)

⸻

17. Debug & Counters (VGM)

By --counters moet VGM metrics bevat:
	•	vgm_commands_total
	•	vgm_psg_writes_total
	•	vgm_wait_events_total
	•	vgm_wait_samples_total
	•	vgm_loops_total

Definisies:
	•	commands_total tel alle commands (ook waits)
	•	psg_writes_total tel 0x50 writes
	•	wait_events_total tel elke wait command event
	•	wait_samples_total tel som van effektiewe wait samples (ná SR scaling + speed factor)

⸻

18. Sanity Checks (VERPLIGTEND)

18.1 Regressie (v0.05 tests MOET bly werk)
	1.	Audio path:

	•	python sn76489_emulator.py --test beep

	2.	Multi-chip + panning:

	•	python sn76489_emulator.py --test beep --chips 2 --pan left
	•	python sn76489_emulator.py --test beep --chips 2 --pan right

	3.	Noise determinisme:

	•	python sn76489_emulator.py --test noise --noise-mode white --noise-rate div32 --noise-seed 0x4000
	•	run 2×, output moet identies klink

	4.	Sequence + ADSR-lite:

	•	python sn76489_emulator.py --test sequence --attack-ms 5 --decay-ms 80 --sustain-vol 8 --release-ms 120

	5.	Chords:

	•	python sn76489_emulator.py --test chords --attack-ms 5 --decay-ms 60 --sustain-vol 8 --release-ms 180

	6.	Sweep:

	•	python sn76489_emulator.py --test sweep --seconds 2

18.2 VGM checks (v0.06)
	1.	List dir:

	•	python sn76489_emulator.py --vgm-list --vgm-base-dir <path>

	2.	Play once:

	•	python sn76489_emulator.py --vgm-path <file>

	3.	Loop:

	•	python sn76489_emulator.py --vgm-path <file> --vgm-loop

	4.	Speed:

	•	python sn76489_emulator.py --vgm-path <file> --vgm-speed 0.5
	•	python sn76489_emulator.py --vgm-path <file> --vgm-speed 2.0

	5.	Counters/dump:

	•	python sn76489_emulator.py --vgm-path <file> --counters --dump-regs

Pass kriteria:
	•	hoorbare klank
	•	geen crash/hang
	•	counters toon VGM metrics
	•	Ctrl+C stop skoon (vir loop)

Fail kriteria:
	•	geen geluid
	•	unsupported command errors op bekende goeie VGM (dan subset te klein)
	•	determinisme breek

⸻

19. Github Kontrak

19.1 README

README moet dokumenteer:
	•	installasie
	•	tests
	•	MIDI
	•	VGM flags (path/base-dir/list/loop/speed)
	•	sanity checklist (copy/paste)

19.2 Commit Style (ASCII + code block)

Vaste commit message styl vir v0.06:
git commit -m "v0.06: add VGM playback (path/list/loop/speed) with counters; keep MIDI+tests stable"
20. Bewus Uitgesluit (v0.06)
	•	Cycle-perfect timing
	•	Volledige VGM spec / alle commands
	•	Multi-chip VGM routing
	•	Seek/rewind
	•	DSP effects
	•	VST/AU

⸻

21. Vervolgkeuse

ies een:
	1.	TS v1.5.1 verfyn
→ “TS pas aan: …”
	2.	TS v1.5.1 goedkeur
→ Ek genereer SN76489 Emulator v0.06 code (nog steeds één Python-bestand), plus:

	•	GitHub README (v0.06)
	•	Install notes
	•	Sanity check checklist (copy/paste)
	•	Rollback hint na v0.05-known-good

	3.	Stop hier / refleksie

TS v1.5.1 goedkeur

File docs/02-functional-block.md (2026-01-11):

---

## 2. Interfaces per blok

### 2.1 USB → ESP32-C2
- Protocol: USB MIDI
- Inputs: MIDI Note On/Off, velocity, channel
- Output: geen (audio gaat analoog)
- Debug: USB serial (REPL/logging)

### 2.2 ESP32-C2 → I2C bus
- Bus: I2C, 100 kHz
- Devices op bus:
  - PCF8574 (parallel expander)
  - OLED display
- Eisen:
  - I2C mag synth timing niet blokkeren
  - OLED updates “low priority”

### 2.3 PCF8574 → SN76489 (parallel + control)
- Data: D0..D7 (8-bit)
- Control:
  - WE / strobe (write enable)
  - (eventueel CE, afhankelijk van SN76489 variant/board)
- Eisen:
  - Data moet stabiel zijn vóór de write-strobe
  - Geen bus-sharing in V1

### 2.4 SN76489 → Audio keten
- Output: mono analoog
- Vereist:
  - AC-koppeling
  - Basis filtering/ontkoppeling
  - Potmeter vóór versterker

### 2.5 Audio amp → TRS jack
- Output: dual-mono L/R (identiek signaal)
- Vereist:
  - DC-blokkering naar koptelefoon
  - serie-R per kanaal (stabiliteit/bescherming)

---

## 3. Timing & enable-volgorde (minimaal noodzakelijk)

Doel: betrouwbare writes naar SN76489 via PCF8574.

### 3.1 Write-sequence (abstract)
Voor elke SN76489 “byte write”:

1. **Zet data-byte** op PCF8574 outputs (D0..D7)
2. **Wacht korte settle-time** (microseconden-orde)
3. **Pulse WE/strobe** (actief laag of hoog afhankelijk van wiring)
4. **Wacht korte hold-time**
5. (optioneel) WE terug naar idle

Belangrijk:
- PCF8574 is I2C-gedreven → writes zijn relatief “traag”
- Dat is oké: SN76489 register writes hoeven niet snel, wél consistent

### 3.2 Update-rate (richtlijn)
- Note events: direct verwerken
- Pitch/volume: bij Note On/Off en (optioneel) aftertouch/velocity mapping
- OLED: max ~10 updates/sec (niet meer)

---

## 4. Voice-mapping (functionele routing)

### 4.1 Basis V1 voice policy
- 3 tone channels: CH0, CH1, CH2
- 1 noise channel: CH3

### 4.2 MIDI channel gedrag (V1)
- MIDI Channel bepaalt:
  - óf “part” selectie (bijv. ch1→tone, ch10→noise)
  - óf simpel: alle MIDI kanalen sturen dezelfde 3 tone voices (round-robin)
- Keuze wordt in firmware vastgelegd; hardware-onafhankelijk

### 4.3 Voice allocatie (simpel)
- Round-robin over CH0-CH2
- Note Off: mute kanaal als die noot actief was
- Noise kanaal: alleen op afgesproken MIDI channel of vaste note-range

---

## 5. Meetpunten (breadboard/debug-first)

### MP0 — USB enumeratie
- Verwachting: device verschijnt als USB MIDI
- Test: DAW/MIDI monitor ziet Note On/Off

### MP1 — I2C gezondheid
- Verwachting: OLED reageert, PCF8574 ACKt
- Test: I2C scan / simpele write test

### MP2 — PCF8574 outputs
- Verwachting: D0..D7 togglen bij writes
- Test: scope op 1–2 datalijnen + strobe

### MP3 — SN76489 control
- Verwachting: strobe pulses zichtbaar
- Test: scope op WE/strobe

### MP4 — SN76489 audio
- Verwachting: toon zichtbaar op scope (klein AC signaal)
- Test: scope AC-coupled, luister via tijdelijke versterker

### MP5 — Post-filter / potmeter wiper
- Verwachting: signaal amplitude verandert met pot
- Test: scope op wiper

### MP6 — Headphone out L/R
- Verwachting: L = R identiek (dual-mono)
- Test: scope op tip en ring, zelfde amplitude/fase

---

## 6. Faalmodi (wat er typisch misgaat)

- Geen geluid maar wel MIDI:
  - SN76489 krijgt geen writes (MP2/MP3 check)
- OLED werkt, maar SN76489 niet:
  - PCF8574 adres / wiring fout (MP1/MP2)
- Geluid maar veel ruis/piep:
  - grounding / decoupling / audio routing (MP4–MP6)
- Volume doet niks:
  - pot verkeerd aangesloten (MP5)

---

## 7. Succescriteria Stap 3

Stap 3 is geslaagd als:
- Elk blok een duidelijke in/uit interface heeft
- Write-volgorde expliciet is (data → settle → strobe)
- Meetpunten vastliggen en logisch zijn
- Breadboard-ontwerp direct uit dit blokdiagram volgt

---

## Volgende stap
**Stap 4 – Breadboard-ontwerp + meetplan**

- concrete module/IC plaatsing
- wiring-strategie (kort, logisch, meetbaar)
- eerste testprocedure van MP0 → MP6

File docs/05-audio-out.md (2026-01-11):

# Stap 5 – Audio-versterkeropties (evaluatie)

Deze stap vergelijkt en borgt mogelijke audio-eindtrappen voor de
SN76489 USB-MIDI synth.

Ontwerpregel (afdwingend):
- Eerst breadboard valideren
- Daarna pas PCB
- Alles meetbaar met scope en multimeter
- Koptelefoon is primaire load

---

## Optie A — LM386 (baseline / educatief)
*(Nog uit te werken)*

Gebruik:
- Snelle proof-of-concept
- Leren waarom dit vaak ruisgevoelig is

---

## Optie B — Opamp-based headphone driver (AANBEVOLEN)

Mono → gebufferd → dual-mono L/R  
Single-supply 5 V met virtuele ground (Vref)

### Status
✅ Technisch verankerd  
✅ Breadboard-geschikt  
✅ Lage ruis, voorspelbaar gedrag  

---

### 1. Conceptueel schema (tekstueel)

SN76489 audio out  
→ AC-koppeling  
→ bias naar Vref (virtuele ground)  
→ opamp gain stage (niet-inverterend)  
→ serieweerstanden  
→ DC-blokkering  
→ dual-mono L/R  
→ 3.5 mm TRS koptelefoon

Audio werkt rond Vref (~2.5 V), niet rond echte ground.

---

### 2. Aanbevolen opamp (THT)

**LM358 (DIP-8)**  
- Werkt op 5 V single-supply  
- Overal verkrijgbaar  
- Acceptabele prestaties voor V1

Opmerking:
- Niet audiofiel
- Kan bij lage impedanties vervormen
- Goed genoeg om het concept te bewijzen

---

### 3. Virtuele ground (Vref)

#### Basis
- R1 = 10 kΩ → +5 V  
- R2 = 10 kΩ → GND  
- Vref ≈ 2.5 V  
- Cref = 47–100 µF naar GND  

#### Aanbevolen
- Buffer Vref met tweede opamp (volger)
- Voorkomt instorten van referentie bij belasting

Zonder stabiele Vref:
→ brom  
→ asymmetrische clipping  
→ onvoorspelbaar gedrag

---

### 4. Ingangskoppeling & bias

- C_in = 1 µF (film of elco)
- R_bias = 100 kΩ van opamp + ingang naar Vref

High-pass:
- f_c ≈ 1.6 Hz  
- Geen hoorbaar laagverlies

---

### 5. Gain-instelling

Niet-inverterend:

Gain = 1 + (Rf / Rg)

Startwaarden:
- Rg = 10 kΩ  
- Rf = 100 kΩ  
- Gain ≈ 11×

Aanpasbaar:
- Te luid / clipping → Rf verlagen (bijv. 47 kΩ)

---

### 6. Uitgang naar koptelefoon (dual-mono)

Per kanaal:
- R_out = 47 Ω (serie)
- C_out = 220–470 µF (DC-blokkering)
- R_bleed = 100 kΩ naar GND

Waarom:
- Bescherming opamp
- Minder ploppen
- Stabiliteit bij pluggen

---

### 7. Verwacht outputniveau

Indicatief:
- SN76489: ~200 mVpp
- Na versterking: ~2.2 Vpp (intern)
- Op koptelefoon: ~1 Vpp AC

Voldoende luid voor 16–64 Ω koptelefoons  
Volume wordt geregeld **vóór** de versterker (potmeter).

---

### 8. Ruis & kwaliteit

**Voordelen**
- Veel stiller dan LM386
- Gain exact instelbaar
- Geen “motorboating”

**Risico’s**
- LM358 beperkte output-drive
- Slechte Vref → hoorbare ellende
- Breadboard-parasieten → oscillatie

---

### 9. Breadboard-risico’s

- Lange draden op opamp-inputs
- Geen lokale 100 nF ontkoppeling
- Vergeten Cref of C_out
- Geen R_out → HF-oscillatie

---

### 10. PCB-layout aandachtspunten

- Vref als apart analoog eiland
- Ster-ground (audio ≠ MCU retour)
- Decoupling direct bij opamp
- Geen digitale sporen onder audio-inputs

---

### 11. Waarom deze optie kan falen

- Onvoldoende output-drive bij lage impedantie
- Virtuele ground instort
- Te hoge gain → clipping
- Oscillatie door layout of breadboard

---

### 12. Meetplan (verplicht)

**Multimeter**
- +5 V rail: 4.9–5.1 V
- Vref: ~2.5 V stabiel
- Opamp output idle: ~2.5 V

**Oscilloscoop**
- SN76489 audio: klein AC-signaal
- Opamp output: groter signaal rond Vref
- Jack-tip na C_out: AC rond 0 V
- Controle op HF-oscillatie

**Luistertest**
- Volume dicht: bijna stil
- Volume open: helder, geen brom of piep

---

### 13. Start-BOM (THT-only)

- LM358 (DIP-8)
- Weerstanden:
  - 10 kΩ ×2 (Vref)
  - 10 kΩ (Rg)
  - 100 kΩ ×2 (Rf, R_bias)
  - 47 Ω ×2 (R_out)
  - 100 kΩ ×2 (R_bleed)
- Condensatoren:
  - 100 nF ×1 (ontkoppeling)
  - 47–100 µF ×1 (Cref)
  - 1 µF ×1 (C_in)
  - 220–470 µF ×2 (C_out)
- Potmeter: 10–50 kΩ log (mono)
- 3.5 mm TRS jack (THT)

---

## Optie C — Dedicated headphone amp IC
*(Nog uit te werken)*

---

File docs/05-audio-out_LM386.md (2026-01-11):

## Optie A — LM386 (baseline / budget / educatief)

Mono → power-amp → dual-mono L/R  
Doel: snel geluid uit een speaker-amp IC, maar met duidelijke nadelen voor koptelefoon.

### Status
✅ Snelste proof-of-concept  
⚠️ Ruisgevoelig / layout-kritisch  
⚠️ Niet ideaal als headphone driver (maar kan “werken” met beperkingen)

---

### 1. Conceptueel schema (tekstueel)

SN76489 audio out  
→ AC-koppeling (C_in)  
→ volumepotmeter (mono)  
→ LM386 input (pin 3)  
→ LM386 output (pin 5)  
→ uitgangsnetwerk (Zobel + decoupling)  
→ DC-blokkering naar koptelefoon L/R (dual-mono)  
→ 3.5 mm TRS jack

Belangrijk:
- LM386 is een **power amp** voor luidsprekers (typisch 8 Ω).
- Koptelefoon (16–64 Ω) is “mogelijk”, maar het gedrag is minder netjes.

---

### 2. Voeding & basisrandvoorwaarden

- VCC: **5 V** (kan ook hoger, maar jouw systeem is 5 V-gedreven)
- Decoupling direct bij IC:
  - 100 nF keramisch
  - 220–470 µF elco op de 5 V rail dichtbij de LM386

Eis:
- LM386 krijgt een eigen “power-eiland” op breadboard.
- Geen voeding via lange spaghetti-jumpers zonder bufferelco.

---

### 3. Gain (verwachte versterking)

LM386 gain:
- Default: **20×** (26 dB) zonder onderdelen tussen pin 1 en 8
- Met C_gain tussen pin 1 en 8: **tot 200×** (46 dB)

Aanbevolen voor deze toepassing:
- **Laat gain op 20×** (dus géén C_gain).
- Waarom: SN76489 is al ruisgevoelig, LM386 versterkt rommel graag mee.

Als het niveau te laag is:
- Eerst potmeter / inputniveau / filtering optimaliseren
- Pas als laatste overweeg je C_gain (en dan krijg je meestal ruis + instabiliteit erbij)

---

### 4. Ingangskoppeling & volumeregeling

- C_in: **100 nF – 1 µF** in serie naar LM386 input
- Potmeter: **10 kΩ log** (mono) als volumeregelaar vóór LM386
- Input bias/stabiliteit:
  - R_in = 10 kΩ–100 kΩ van input naar GND (optioneel, tegen zweven)

Praktisch startpunt:
- C_in = 100 nF of 220 nF
- Pot = 10 kΩ log

---

### 5. Uitgang naar koptelefoon (dual-mono)

LM386 output is biased (intern) en kan DC bevatten → **DC blokkeren**.

Per kanaal:
- C_outL = 220–470 µF in serie naar L
- C_outR = 220–470 µF in serie naar R

Aanbevolen extra bescherming:
- R_outL = 33–100 Ω serie naar L
- R_outR = 33–100 Ω serie naar R

Waarom:
- Beperkt stroom
- Minder kans op “schelle” vervorming
- Minder kans op instabiliteit bij vreemde loads/kabels

Bleeders:
- R_bleedL = 100 kΩ van L naar GND
- R_bleedR = 100 kΩ van R naar GND

---

### 6. Standaard stabiliteitsnetwerken (verplicht bij LM386)

**Bypass (ruisreductie)**
- Pin 7 → C_bypass = **10 µF** naar GND  
Dit kan ruis/hum merkbaar verminderen.

**Zobel netwerk (tegen oscillatie, output stabiliteit)**
- Vanaf output (pin 5) naar GND:
  - R_zobel = **10 Ω**
  - C_zobel = **47 nF**
  (in serie)

**Output snubber / extra**
- Soms helpt een kleine L (spoeltje) of serieweerstand; op breadboard liever R_out gebruiken.

---

### 7. Verwacht outputniveau

Bij 5 V:
- LM386 kan voldoende niveau leveren om koptelefoon luid te maken,
  maar headroom is beperkt en vervorming kan snel oplopen.

Praktische verwachting:
- Genoeg volume, maar eerder:
  - ruisvloer hoorbaar
  - “korrelig” bij hoge gain
  - sneller clippen

---

### 8. Ruis & brongevoeligheid

**Voordelen**
- Simpel
- Werkt snel
- Veel voorbeeldschakelingen

**Nadelen**
- Versterkt ruis en voeding-rommel makkelijk mee
- Gevoelig voor layout en ontkoppeling
- Kan “motorboaten” (laagfrequente oscillatie) bij slechte voeding/decoupling
- Niet ontworpen voor nette koptelefoonkwaliteit

---

### 9. Breadboard-risico’s

Waar het misgaat (klassiek LM386):
- Voedingsdraden te lang → oscillatie / motorboating
- Ontkoppeling te ver weg → brom/ruis
- Geen Zobel → HF-oscillatie
- Te hoge gain (C_gain geplaatst) → ruis + instabiliteit
- Audio-ground en digitale ground door elkaar → digitale piepjes

Kort: LM386 op breadboard is vaak “een les in grounding”.

---

### 10. PCB-layout aandachtspunten

- **Heel korte** decoupling-loop VCC ↔ GND bij IC
- Output trace weg van input trace (geen feedback via koppeling)
- Ster-ground: audio retour niet door MCU groundsporen
- Zobel dicht bij output-pin en ground return
- Pin 7 bypass cap dichtbij pin 7

LM386 is berucht: layout bepaalt of het stil is of een zender.

---

### 11. Waarom deze optie kan falen (eerlijk)

- **Oscillatie** (HF) → hiss / warmte / rare vervorming
- **Motorboating** → “woef-woef” op lage frequentie
- **Brom** door ground loops
- **Clippen** door beperkte headroom op 5 V
- **Koptelefoon mismatch**: te hard, te ruw, te veel ruis

---

### 12. Meetplan (verplicht)

**Multimeter**
- +5 V rail: 4.9–5.1 V
- Controleer dat pin 6 stabiel 5 V ziet (geen dips bij audio)

**Oscilloscoop**
1. Meet output op pin 5 zonder load:
   - Kijk of er HF-oscillatie “haar” zichtbaar is
2. Meet met koptelefoon aangesloten:
   - Kijk of de golf instort / asymmetrisch wordt
3. Meet voeding bij LM386:
   - Kijk naar dips en rimpel tijdens audio (motorboating herken je zo)

**Luistertest**
- Volume dicht → ruisvloer checken
- Volume open → check op brom, piep, “woef”-oscillatie

---

### 13. Start-BOM (THT-only)

- LM386 (DIP-8)
- Weerstanden:
  - 10 Ω (Zobel)
  - 33–100 Ω ×2 (R_out L/R)
  - 100 kΩ ×2 (R_bleed L/R)
  - (optioneel) 10–100 kΩ (R_in naar GND)
- Condensatoren:
  - 100 nF (VCC decouple)
  - 220–470 µF (VCC bulk dichtbij IC)
  - 10 µF (pin 7 bypass)
  - 47 nF (Zobel)
  - 100 nF–1 µF (C_in)
  - 220–470 µF ×2 (C_out L/R)
- Potmeter: 10 kΩ log (mono)
- 3.5 mm TRS jack (THT)

---

### 14. Wanneer kiezen (beslisregel)

Kies Optie A als:
- Je vandaag nog geluid wil en bereid bent ruis/layout-issues te debuggen
- Je educatief wil ervaren waarom LM386 “tricky” is

Kies Optie B als:
- Je een stabiele eindoplossing wil die echt koptelefoonvriendelijk is
- Je controle wil over gain en ruis

---

## Optie A vs Optie B — Vergelijkingsmatrix

| Aspect | Optie A — LM386 | Optie B — Opamp-based |
|---|---|---|
| Primair doel | Speaker amp hergebruikt voor audio | Headphone-geschikte line/driver |
| Complexiteit | Laag (op papier) | Middel |
| Aantal onderdelen | Laag | Middel |
| Voeding | 5 V single-supply | 5 V single-supply |
| Gain-controle | Beperkt (20× / 200×) | Volledig instelbaar |
| Ruisvloer | Hoog / wisselend | Laag / voorspelbaar |
| Bromgevoeligheid | Hoog | Laag |
| Oscillatie-risico | Hoog (layout-kritisch) | Laag–middel |
| Breadboard-geschiktheid | ⚠️ Fragiel | ✅ Goed |
| Koptelefoon-geschikt | ⚠️ Matig | ✅ Ja |
| Output-impedantie | Laag maar ongecontroleerd | Gecontroleerd (R_out) |
| DC-beveiliging | Vereist extra aandacht | Ingebouwd via C_out |
| Debugbaarheid | Lastig (veel bijeffecten) | Goed (meetbaar per blok) |
| Educatieve waarde | “Waarom dit fout kan gaan” | “Zo bouw je het netjes” |
| Kans op succes V1 | ⚠️ 50/50 | ✅ Hoog |
| Geschikt als eindoplossing | ❌ Nee | ✅ Ja |

---

### Samenvattende beslisregel

- **Optie A (LM386)**  
  Gebruik als:
  - snelle proof-of-concept  
  - educatief experiment  
  - je expliciet wilt leren *waarom* dit IC vaak problemen geeft  

- **Optie B (Opamp-based)**  
  Gebruik als:
  - stabiele breadboard-validatie  
  - koptelefoon primaire output is  
  - je richting een nette PCB-oplossing werkt  

**Ontwerpkeuze V6 (aanbevolen):**  
➡️ *Optie B is het hoofdpad.*  
➡️ *Optie A blijft referentie / vergelijking.*

---

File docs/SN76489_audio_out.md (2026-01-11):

# ASCII-schema — SN76489 audio-out + AC-koppeling (V1)

Doel:
- SN76489 **mono audio** netjes uit de chip halen
- **DC blokkeren** en ruis/rommel beperken
- Signaal correct aanbieden aan:
  - volumepot (vóór versterker)
  - versterker (Optie B aanbevolen)
  - dual-mono koptelefoon-out

---

## 1. Minimalistisch en werkend (V1 “bring-up”)

Dit is de snelste variant die meestal meteen geluid geeft.

SN76489
AUDIO OUT (pin 12)
│
│   C_IN 1µF–10µF  (AC-koppeling, + richting chip bij elco)
├──||───●───────────────> naar volumepot “TOP”
│       │
│       R_BIAS 100k
│       │
GND ─────┴────────────────> GND_AUD

**Wat dit doet**
- `C_IN` blokkeert DC uit de chip
- `R_BIAS` voorkomt zweven/ploppen en definieert impedantie

**Startwaarden**
- `C_IN = 1 µF` (film als je hebt, anders elco)
- `R_BIAS = 100 kΩ`

---

## 2. Aanbevolen V1 audio-pad (met volumepot vóór amp)

SN76489 pin 12 (AUDIO)
│
│  C_IN 1µF–10µF
├──||───────●───────────────> POT_TOP
│           │
│           R_BIAS 100k
│           │
GND_AUD────────┴────────────────> POT_GND

### Volumepot (mono, 10k–50k log)
POT_TOP  o—–> audio in
POT_WIPER o––> AUDIO_POST_POT (naar versterker)
POT_GND  o—–> GND_AUD

**Praktisch advies**
- Potmeter: **10 kΩ log** is een goede default
- Wiper is je meetpunt **MP5**

---

## 3. Optie B ingang (opamp met virtuele ground) — correct koppelen

Als je Optie B gebruikt (opamp + Vref), dan wil je de input **rond Vref biasen**.

AUDIO_POST_POT
│
│  C_OPIN 100n–1µF   (AC-koppeling naar opamp-input)
├──||──●──────────────> opamp + input
│      │
│      R_TO_VREF 100k
│      │
VREF_AUD (2.5V) ———> (virtuele ground)

**Waarom**  
- Opamp kan niet onder 0 V op single-supply  
- Dus je centreert audio rond **VREF_AUD**

---

## 4. Koptelefoon dual-mono uitgang (na versterker, DC-safe)

Na de versterker wil je **geen DC** naar je koptelefoon.

AMP_OUT
│
├─ R_OUT_L 47Ω ──|| C_OUT_L 220–470µF ──> TIP (L)
│
└─ R_OUT_R 47Ω ──|| C_OUT_R 220–470µF ──> RING (R)

SLEEVE –––––––––––––––––> GND_AUD

(aanrader tegen plop)
TIP  ── R_BLEED_L 100k ──> GND_AUD
RING ── R_BLEED_R 100k ──> GND_AUD

**Startwaarden**
- `R_OUT = 47 Ω`
- `C_OUT = 220 µF` (32 Ω → fc ~ 22 Hz)  
  Wil je meer laag: `470 µF`
- `R_BLEED = 100 kΩ`

---

## 5. Waar het vaak fout gaat (snelle checklist)

- ❌ `C_IN` te ver van SN76489 → pikt digitale rommel op  
  ✅ zet `C_IN` fysiek **dicht bij pin 12**
- ❌ audio ground via digitale ground terug  
  ✅ `GND_AUD` star-point bij power entry
- ❌ geen bias/bleeder → ploppen, zweven  
  ✅ `R_BIAS` en `R_BLEED` plaatsen
- ❌ DC naar koptelefoon  
  ✅ altijd `C_OUT` in serie naar L/R

---

## 6. Meetpunten (scope)

- **MP4:** direct op SN76489 pin 12 → klein AC signaal  
- **MP5:** pot-wiper → amplitude verandert met pot  
- **MP6:** tip en ring → identiek, DC ~ 0 V

---

## Aanbevolen componenten (THT)

- C_IN: 1 µF (film) of elco
- R_BIAS: 100 kΩ
- Pot: 10–50 kΩ log
- R_OUT: 47 Ω (2×)
- C_OUT: 220–470 µF (2×)
- R_BLEED: 100 kΩ (2×)

---

Als je wilt, maak ik hierna ook een **ASCII “layout hint”** (waar je C_IN en R_BIAS fysiek op breadboard moet zetten om digitale piep te vermijden).

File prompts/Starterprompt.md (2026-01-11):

Je bent een ervaren hobby-elektronica ontwikkelaar en educator, in de stijl van GreatScott op YouTube:
pragmatisch, technisch eerlijk, nieuwsgierig en iteratief.

## Projectcontext
Ik bouw een DIY MIDI-synth op basis van de SN76489 sound chip en een ESP32 Wemos Mini series board.

---

## Ontwerpfundament (ZEER BELANGRIJK)
⚠️ In tegenstelling tot eerdere iteraties is **STAP 1 altijd het KiCad hardware-ontwerp**.
Geen abstractie, geen firmware, geen UX vóórdat het schema klopt.

---

## Stap 1 — Verplicht KiCad-hoofdontwerp (start hier)
Ontwerp in KiCad 8.0 een **volledig through-hole schema** met de volgende vaste keten:

ESP32 Wemos Mini (USB MIDI)
→ PCF8574 (I2C I/O expander, DIP)
→ SN76489 (PSG, DIP)
→ LM386 (mono audio amp, DIP)
→ dual-mono booster (bijv. SAM / PAM / audio breakout board met pinheaders)
→ variabel volume (potmeter, master volume)
→ 3.5 mm TRS headphone audio out jack (L+R gedupliceerd)

### Hardware-eisen
- Alleen through-hole componenten of breakout boards
- Geen losse SMD-componenten
- Hand-soldeerbaar
- Breadboard-compatibel ontwerp
- Duidelijke netlabels (DATA, WR, CS, CLK, AUDIO, GND, VCC)

---

## Extra hardware: gebruikersinterface
Het ontwerp bevat ook:

### SSD1302 / SSD1306 I2C mini LCD
- Interface: I2C (gedeeld met PCF8574)
- Functie:
  - tonen van MIDI-kanaal
  - huidige noot
  - volume-indicatie (logisch, niet elektrisch)
  - statusmeldingen (USB/MIDI actief)
- Benoem:
  - I2C-adressering
  - pull-up strategie
  - conflicten met PCF8574

---

## Verplicht signaalpad (audio)
- SN76489 audio-output wordt als **mono** beschouwd
- LM386 versterkt mono signaal
- Dual-mono booster dupliceert naar L + R
- Volume wordt **analoog geregeld via potmeter**
- TRS jack:
  - Tip = Left
  - Ring = Right
  - Sleeve = GND
- Geen digitale volume-regeling

---

## Ontwerpaanpak (afdwingend)
1. **KiCad schema ontwerpen (STAP 1, GEEN UITZONDERING)**
2. Controleren op:
   - voedingsspanningen
   - I2C busdeling
   - ground-referenties
   - audio signaalniveau
3. Pas daarna:
   - breadboard mapping
   - teststrategie
   - firmware-architectuur
   - UX-logica

---

## Beschikbare middelen (verplicht meenemen)
- KiCad 8.0
- Breadboards + jumper wires
- Riden RC6006 labvoeding
- RIGOL DHO804 oscilloscoop
- Aneng SZ02 multimeter
- 3D-printer (behuizing, frontpaneel)
- MCU’s:
  - ESP32 Wemos Mini series (primair)
  - ESP32-S2 / ESP32-C3 / RP2040 (optioneel)

Gebruik deze middelen actief bij:
- ontwerpbeslissingen
- debug-strategieën
- meetplannen

---

## Taken (strikte volgorde)
1. KiCad schema (volledig, through-hole)
2. Annotatie & uitleg van elk blok
3. Breadboard-vertaling + meetpunten
4. Audio-testplan (ruis, gain, clipping)
5. LCD UI-signalen & I2C-conflictanalyse
6. Firmware-architectuur (CircuitPython)
7. Test & debug checklist
8. Verbeter-voorstellen + vervolgvragen

---

## Educatieve insteek
- Leg keuzes uit alsof dit een YouTube-aflevering is
- Benoem expliciet: “dit is waarom dit fout kan gaan”
- Splits het project in duidelijke milestones
- Benoem wat bewust niet wordt gedaan en waarom

## Stijl
- Markdown waar nuttig
- Geen marketingtaal
- Camera-proof uitleg
- Blijf verbeteren tot ik “stop” zeg

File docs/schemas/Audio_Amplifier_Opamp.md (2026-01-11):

# Audio_Amplifier_Opamp.sch — (Optie B) opamp + VREF

> In V1 doen we **mono** versterking en daarna split naar dual-mono.

### Voeding & referentie
+5V_AUD ────────────────┐
│
R3 10k
│
├─────> VREF_AUD (≈2.5V) ──|| C3 47u ──> GND_AUD
│
R4 10k
│
GND_AUD ─────────────────┘

### Signaal (block-level)
**Netten die hier “vast” moeten zijn:**
- `+5V_AUD`, `GND_AUD`, `VREF_AUD`
- `AUDIO_POST_POT` (in)
- `AUDIO_AMP_OUT` (uit)

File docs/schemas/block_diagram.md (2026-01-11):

# End-to-end verbindingen (gevraagd expliciet)

## 1) ESP32-S2 → PCF8574(AP)

ESP32 SDA ───────────────> PCF SDA
ESP32 SCL ───────────────> PCF SCL
+5V_IN  ────────────────> +5V_DIG → PCF VCC
GND_IN  ────────────────> GND_DIG → PCF GND
SDA/SCL pullups: 4k7 naar +5V_DIG

## 2) PCF8574(AP) → SN76489
PCF P0..P7 ─────────────> SN D0..D7 (pins 1..8)
PCF WE_STROBE ──────────> SN WE (pin 9)
SN CE (pin 11) ─────────> GND_DIG
SN CLK (pin 10) ─────────> SN_CLK (extern of module)

## 3) SN76489 → audio-architectuur
SN AUDIO OUT (pin 12) ──> PSG_AUDIO_RAW
PSG_AUDIO_RAW ── C_IN ──> AUDIO_IN ──> pot ──> AUDIO_POST_POT ──> opamp ──> AUDIO_AMP_OUT
AUDIO_AMP_OUT ──> (R_OUT + C_OUT) ──> TRS TIP/RING (dual-mono)
TRS SLEEVE ──> GND_AUD

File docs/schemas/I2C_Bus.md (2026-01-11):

## I2C_Bus.sch — ESP32-S2 → PCF8574(AP) (+ OLED)

### I²C bus + pullups
SDA ──┬──────────> PCF8574 SDA
└──────────> OLED SDA
|
└─ R1 4k7 ──> +5V_DIG

SCL ──┬──────────> PCF8574 SCL
└──────────> OLED SCL
|
└─ R2 4k7 ──> +5V_DIG

PCF8574 VCC → +5V_DIG
PCF8574 GND → GND_DIG
OLED VCC    → +5V_DIG (of 3V3 als jouw display dat vereist)
OLED GND    → GND_DIG

### PCF8574(AP) pinout (DIP-16, functioneel)
*(Pin-nummers kunnen per fabrikant gelijk zijn, maar gebruik dit als “kaart” voor je wiring)*

### PCF8574(AP) pinout (DIP-16, functioneel)
*(Pin-nummers kunnen per fabrikant gelijk zijn, maar gebruik dit als “kaart” voor je wiring)*

PCF8574(AP) (DIP-16) — kernsignalen
SDA, SCL : I2C bus
A0,A1,A2 : adresselectie (naar GND of +5V_DIG)
P0..P7   : 8 GPIO’s → SN76489 data/strobe
INT      : (optioneel) interrupt naar MCU (niet nodig in V1)
VCC      : +5V_DIG
GND      : GND_DIG

### Parallel uit (PCF → SN)
**Aanbevolen mapping:**

PCF P0 → D0 (SN pin 1)
PCF P1 → D1 (SN pin 2)
PCF P2 → D2 (SN pin 3)
PCF P3 → D3 (SN pin 4)
PCF P4 → D4 (SN pin 5)
PCF P5 → D5 (SN pin 6)
PCF P6 → D6 (SN pin 7)
PCF P7 → D7 (SN pin 8)

WE_STROBE (PCF bit, vaak P7 of extra gating) → WE (SN pin 9)

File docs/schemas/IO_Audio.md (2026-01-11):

# IO_Audio.sch — SN76489 audio → AC-koppeling → pot → amp → TRS

### SN audio-out + AC-koppeling (direct bij chip)

PSG_AUDIO_RAW
│
├──|| C_IN (C4) 1u–10u ──●──> AUDIO_IN
│                        │
│                      R_BIAS (R5) 100k
│                        │
GND_AUD ────────────────────┘

### Volumepot (extern via header J4)
J4 POT_VOL (3-pin)
Pin1: POT_TOP   ← AUDIO_IN
Pin2: POT_WIPER → AUDIO_POST_POT
Pin3: POT_GND   → GND_AUD

### Amp output naar dual-mono koptelefoon
AUDIO_AMP_OUT
├─ R_OUT_L (R6) 47Ω ──|| C_OUT_L (C5) 220–470u ──> AUDIO_L ──> TRS TIP
└─ R_OUT_R (R7) 47Ω ──|| C_OUT_R (C6) 220–470u ──> AUDIO_R ──> TRS RING

TRS SLEEVE → GND_AUD

(anti-plop)
AUDIO_L ── R_BLEED_L 100k ──> GND_AUD
AUDIO_R ── R_BLEED_R 100k ──> GND_AUD

# ASCII-schema — SN76489 → LM386 (gain = 20 dB) + “LM_AUDIO” output label

Gebaseerd op TI LM386 datasheet **minimum-parts** layout (Gain = 20 dB) met:
- **Zobel**: 10 Ω + 0.05 µF vanaf output naar GND
- **Output coupling**: 250 µF in serie naar de load  
 [oai_citation:0‡ti.com](https://www.ti.com/lit/ds/symlink/lm386.pdf?utm_source=chatgpt.com)

> Gain = **20 dB** bij LM386 wanneer **pins 1 en 8 open** blijven.  [oai_citation:1‡ti.com](https://www.ti.com/lit/ds/symlink/lm386.pdf?utm_source=chatgpt.com)

---

## 1) SN76489 audio-out → LM386 input (AC-koppeling)
SN76489 (pin 12) PSG_AUDIO_RAW
│
│   C_IN 1µF–10µF  (AC-koppeling; + richting SN als elco)
├──||───●──────────────> LM386 IN+ (pin 3)
│       │
│       R_BIAS 100k
│       │
GND_AUD──┴────────────────> LM386 GND (pin 4)  [en SN GND]

---

## 2) LM386 (PDIP-8) — minimum parts, gain = 20 dB

            LM386 (PDIP-8)
         ┌─────────────────────────┐
GAIN 1  1│                        8│  GAIN 2      (pins 1 & 8 OPEN → gain 20 dB)
IN-     2│                        7│  BYPASS      (optioneel: 10µF naar GND voor minder brom/ruis)
IN+     3│                        6│  +5V
GND     4│                        5│  OUT  =  LM_AUDIO
         └─────────────────────────┘

### Voeding + ontkoppeling (sterk aanbevolen, ook op breadboard)
+5V  ──┬──────────────> LM386 pin 6
│
├──|| 100n ─────> GND
└──|| 100µF ────> GND   (bulk dichtbij IC)

x

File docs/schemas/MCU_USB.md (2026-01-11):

## MCU_USB.sch — ESP32-S2 header naar I²C (en power)

> ESP32-S2 pin-nummers verschillen per board. Dit is **functionele pinout** (headers).  
> Jij koppelt hier alleen: **+5V_IN, GND_IN, SDA, SCL**.

J2 ESP32-S2 HDR (voorbeeld 1x06)
1: +5V_IN   (van USB 5V)
2: GND_IN
3: SDA      (I2C data)
4: SCL      (I2C clock)
5: GPIOx    (optioneel, later)
6: GPIOy    (optioneel, later)

Netten:
J2.1 → +5V_IN
J2.2 → GND_IN
J2.3 → SDA
J2.4 → SCL

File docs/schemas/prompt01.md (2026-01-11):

Voor elk van onderstaand KICAD schemas:
Top.sch
├── Power.sch
├── MCU_USB.sch
├── I2C_Bus.sch
├── PSG_SN76489.sch
├── Audio_Amplifier_Opamp.sch
└── IO_Audio.sch

# Instructie
1. Genereer een ASCII-versie met alle pinouts, verbindinen van bijvb
 -  ESP32 S2 naar de PCF9574AP
 - PCF9574AP naar SN76489
 - SN76489 naar geluid architectuur
2. Output in Github-ready copy-paste formaat.

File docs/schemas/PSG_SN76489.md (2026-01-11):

# PSG_SN76489.sch — PCF8574(AP) → SN76489 + audio out

### SN76489 pinout (DIP-16, klassiek)
        SN76489 (DIP-16)
      ┌─────────────────┐
 D0 ──│ 1            16 │── NC
 D1 ──│ 2            15 │── NC
 D2 ──│ 3            14 │── GND_DIG
 D3 ──│ 4            13 │── +5V_DIG
 D4 ──│ 5            12 │── PSG_AUDIO_RAW
 D5 ──│ 6            11 │── CE
 D6 ──│ 7            10 │── CLK
 D7 ──│ 8             9 │── WE
      └─────────────────┘

### Verbindinen (essentieel)
D0..D7  (SN pins 1..8)  ← PCF P0..P7
WE      (SN pin 9)      ← PCF WE_STROBE
CLK     (SN pin 10)     ← SN_CLK (extern of module-clock)
CE      (SN pin 11)     → GND_DIG  (V1: altijd enabled)
AUDIO   (SN pin 12)     → PSG_AUDIO_RAW (naar audio sheet)
+5V     (SN pin 13)     → +5V_DIG
GND     (SN pin 14)     → GND_DIG

### Decoupling (verplicht, fysiek dicht bij SN)
+5V_DIG ──|| C1 100n ── GND_DIG
+5V_DIG ──|| C2 10u  ── GND_DIG

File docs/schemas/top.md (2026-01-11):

# ASCII “KiCad-style” wiring per sheet (Top + subsheets)
> **NOTE (belangrijk):** jij schreef **PCF9574AP**. In vrijwel alle hobby-modules en datasheets is dit **PCF8574 / PCF8574A / PCF8574AP** (zelfde functie; “A/AP” = ander I²C-adresbereik).  [oai_citation:0‡ti.com](https://www.ti.com/lit/ds/symlink/pcf8574.pdf?utm_source=chatgpt.com)  
> Hieronder ga ik uit van **PCF8574(AP)** als 8-bit I²C GPIO expander.

---

## Top.sch — systeem-overzicht (netten & blokken)
USB 5V/GND
│
├─────────────── +5V_IN ───────────────┐
│                                      │
└─────────────── GND_IN ───────────────┘
│  (STAR-POINT)
┌───────────┴───────────┐
│                       │
+5V_DIG                 +5V_AUD
GND_DIG                 GND_AUD

ESP32-S2 (USB MIDI + I2C master)
├── SDA ───────────────┐
└── SCL ───────────────┘
│
▼
PCF8574(AP)  (I2C→8-bit)
P0..P7 + (WE strobe bit)
│  D0..D7 + WE
▼
SN76489
│  PSG_AUDIO_RAW
▼
AC-koppeling → pot → opamp amp → dual-mono → TRS jack

---

## Power.sch — voeding & star-point

### Pinout / connectors
J1 POWER_IN (2-pin)
Pin1: +5V_IN
Pin2: GND_IN

### Net-splitsing (conceptueel)
+5V_IN  ──┬──> +5V_DIG
└──> +5V_AUD

GND_IN  ──┬──> GND_DIG
└──> GND_AUD

**PCB bedoeling:** +5V en GND splitsen in DIG/AUD en **maar op één punt** samenbrengen (star-point).

---

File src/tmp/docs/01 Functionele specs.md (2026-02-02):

# Funksionele Spesifikasie (FS) v1.6  
## SN76489 PSG Emulasie in Python (MacOS)

Datum: 2 Februarie 2026  
Status: FS v1.6 (uitgebreid, kontrak-dokument)  
Doelplatform: MacOS 26.2  
Python: 3.12  
Huidige stabiele implementasie: v0.05 ✅  

---

## 0. Konteks & Agtergrond

Hierdie projek is ’n **register-gedrewe SN76489 PSG emulasie / engine** in Python.

Belangrike ontwerpbesluit (nie onderhandelbaar nie):
- Alle klank ontstaan **uitsluitlik** deur SN76489-register writes
- Geen direkte DSP tone generators as plaasvervanger vir chipgedrag
- Die emulator dien as:
  - klankgenerator
  - toetsinstrument
  - referensie-implementasie
  - basis vir toekomstige hardware-integrasie

Die projek word iteratief ontwikkel met streng skeiding tussen:
- Funksionele spesifikasie (FS)
- Tegniese spesifikasie (TS)
- Implementasie (code)

---

## 1. Doel

Bou ’n SN76489 PSG engine wat:

- Op MacOS loop
- CLI-first en toetsbaar is
- Deterministies is (reproseerbare output)
- Kan funksioneer as:
  - emulator
  - musikale instrument
  - MIDI-klankbron
  - VGM player
- Iteratief uitbrei volgens vaste fases:
  
  **debug → sequencing → polyfonie → MIDI → VGM → DAW → hardware**

---

## 2. Scope

### 2.1 In scope (huidig + volgende iterasies)

#### Kern-emulasie
- 3× tone-kanale
- 1× noise-kanaal
- Latch/data registergedrag
- Volume, noise modes, clock-dividers
- Mono PCM per chip

#### Engine / platform
- Multi-chip ondersteuning (1–128 SN76489s)
- Stereo routing (left / right / both)
- Mixer + master gain model
- Buffer-gebaseerde audio rendering

#### Runtime modes / CLI
- Tests:
  - `--test beep`
  - `--test noise`
  - `--test sequence`
  - `--test chords`
  - `--test sweep`
- Debug:
  - `--dump-regs`
  - `--counters`
  - `--debug` (rate-limited)

#### MIDI
- CoreMIDI input (MacOS)
- MIDI channel → chip mapping
- Note On / Note Off
- Velocity → volume mapping
- Pitch bend (v0.05)
- Optioneel: sustain pedal (CC64)

#### File playback
- MIDI file playback (later)
- **VGM file playback** (v0.06 fokus)

---

### 2.2 Uitdruklik buite scope (vir nou)

- VST/AU plugins
- Cycle-perfect timing
- DSP effects (reverb, delay, filters)
- Multi-file refactor
- Grafiese UI

---

## 3. Runtime Modes / CLI

CLI is die **primêre beheerlaag** vir:
- ontwikkeling
- regressie
- Copilot-validasie
- dokumentasie

### 3.1 Test modes

- `--test beep`  
  Basiese sanity test (audio path + tone register)

- `--test noise`  
  Noise kanaal, LFSR, rate en seed

- `--test sequence`  
  Vasgestelde note-reeks (melodie)

- `--test chords`  
  3 stemme gelyk (tone0/1/2)

- `--test sweep`  
  Period sweep (bv. 220 → 880 Hz)

---

### 3.2 Debug / Inspectie modes

- `--dump-regs`
  - Alle 8 SN76489 registers
  - Latched register
  - Afgeleide state (frekwensies, volumes)
  - Voice allocation (v0.05+)
  - Envelope states

- `--counters`
  - Register writes
  - Render calls
  - Audio frames
  - MIDI events
  - Envelope steps
  - (later) VGM commands / waits

- `--debug`
  - Mens-leesbare debug output
  - Rate-limited
  - Geen realtime spam

---

## 4. NUUT — Debug Output Gedrag (ADD)

### 4.1 Parameter Echo (verpligtend)

Wanneer `sn76489_emulator.py` met **`--test` parameters** gerun word:

- Alle relevante CLI parameters **MOET eksplisiet na console ge-echo word**
- Doel:
  - visuele bevestiging
  - log-vergelyking
  - regressie-verifikasie

Voorbeeld:
TEST MODE: sequence
chips=1 pan=both
attack-ms=5 decay-ms=80 sustain-vol=8 release-ms=120
block-frames=512 master-gain=0.25

Geen parameter mag “stil” wees tydens tests nie.

---

## 5. SN76489 Core Funksionele Vereistes

- 3 tone-kanale
  - 10-bit period
  - 4-bit volume
- 1 noise-kanaal
  - white / periodic
  - rate: div16/div32/div64/tone2
- Register writes:
  - latch + data bytes
  - tone period updates
  - noise ctrl updates
  - volume updates
- Output:
  - mono PCM per chip

---

## 6. Multi-chip Argitektuur

- 1 tot 128 onafhanklike SN76489s
- Elke chip het:
  - eie registers
  - eie voices
  - eie counters
- Mixer:
  - lineêr O(N)
  - geen gedeelde state
- Per-chip gain + master gain

---

## 7. Stereo Routing

- Per run of per chip:
  - `left`
  - `right`
  - `both`
- `both` = dual-mono (selfde mono na L+R)

---

## 8. Kwaliteit-verbeterings (bestaand)

- `--master-gain`
- `--block-frames`
- `--noise-seed`
- `--noise-rate`
- “Golden” `--dump-regs` output

---

## 9. MIDI (verfyn)

### 9.1 MIDI input
- CoreMIDI
- Channel → chip mapping
- Note On / Off
- Velocity → volume
- Pitch bend
- Optioneel CC64 sustain

### 9.2 NUUT — Eksklusiwiteit (ADD)
- `--midi-in` en `--vgm-path` is **wedersyds eksklusief**
- Program moet hard faal met duidelike foutboodskap indien albei gebruik word

---

## 10. VGM Playback (v0.06 fokus)

### 10.1 Basiese vereistes
- Lees VGM file vanaf disk
- Ondersteun:
  - SN76489 write commands
  - wait / delay commands
- Audio-rate accurate timing is voldoende

---

### 10.2 VGM CLI (ADD)

- `--vgm-path <file>`
  - speel gespesifiseerde VGM onmiddellik

- `--vgm-base-dir <path>`
  - default VGM library directory
  - voorbeeld:
    ```
    /Volumes/data1/Yandex.Disk.localized/michiele/Arduino/PCB Ontwerp/KiCAD/github/SN76489-synth-midi/src/tmp/src/
    ```

- `--vgm-loop`
  - loop playback
  - default: speel 1 keer

- `--vgm-speed <factor>`
  - 1.0 = normaal
  - <1.0 = stadiger
  - >1.0 = vinniger
  - slegs vir debug/analise

- `--vgm-list`
  - lys alle `.vgm` files in `--vgm-base-dir`
  - output na console
  - opsioneel beskikbaar as interne datastruktuur

---

## 11. Debug & Counters (uitgebrei)

Counters moet ook bevat:
- VGM commands processed
- VGM wait ticks
- Loop count

Alles sigbaar via `--counters`.

---

## 12. Github

### 12.1 README (breë publiek)
README moet beskryf:
- wat die projek is
- hoe om te installeer
- hoe om tests te run
- hoe om MIDI te gebruik
- VGM roadmap

### 12.2 Git commit messages (kontrak)
Elke release het ’n vasgestelde commit style.

Voorbeeld:
git commit -m “v0.05: polyphonic voices + ADSR-lite + pitch bend; add chords/sweep tests”
---

## 13. Aanvaaringskriteria (v0.06 – VGM)

- `--vgm-path` speel hoorbare klank
- `--vgm-loop` werk
- `--vgm-speed` beïnvloed tempo
- `--vgm-list` wys files
- Debug counters wys VGM statistiek
- Geen regressie teen v0.05

---

## 14. Vervolgkeuses

1) FS verder verfyn  
2) FS goedkeur → TS v1.5 (VGM playback)  
3) Pas-op-die-plaas / cleanup

---

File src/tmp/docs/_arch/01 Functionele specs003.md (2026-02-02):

# Funksionele Spesifikasie (FS) v1.6  
## SN76489 PSG Emulasie in Python (MacOS)

**Datum:** 2 Februarie 2026  
**Status:** FS v1.6 (verfyn ná goedgekeurde v0.04 + v0.05)  
**Doelplatform:** MacOS 26.2  
**Python:** 3.12  
**Huidige status:** v0.05 stabiel ✅  
- Multi-chip (1–128)  
- Stereo routing (left/right/both)  
- Mixer + gain model  
- CLI: `--chips`, `--pan`, `--master-gain`, `--block-frames`  
- Debug: `--dump-regs`, `--counters`, `--debug` (rate-limited)  
- v0.05: polyfonie + ADSR-lite + pitch bend + `--test chords` + `--test sweep`

---

## 0. Konteks & Status

SN76489 Emulator is ’n **register-gedrewe** PSG engine/emulator in Python, gebou as ’n iteratiewe reeks milestones.

Belangrikste reël:
- Alle klank ontstaan uitsluitlik via **SN76489 register writes**.
- Geen direkte DSP sine generators as “shortcut” vir tone nie.

---

## 1. Doel

Bou ’n **SN76489 PSG emulasie/engine** in Python wat:

- Op MacOS loop
- Live audio na computer speakers uitstuur
- As ’n speelbare instrument kan optree (tests, sequencing, MIDI, later DAW)
- Multi-chip layering en stereo routing ondersteun
- Iteratief uitbrei:  
  **debug → sequencing → multi-chip → file playback (MIDI/VGM) → DAW/MIDI integrasie**

---

## 2. Scope

### 2.1 In scope (huidige + volgende iterasies)

#### Kern-emulasie
- 3× tone + 1× noise per chip
- register latch/data gedrag
- volume, noise modes, mixing
- mono per chip → stereo via routing

#### Engine / platform
- Multi-chip bank (1–128)
- Stereo routing: left/right/both
- Mixer + gain model
- Buffer rendering

#### Runtime modes / CLI
- Tests:
  - `--test beep`
  - `--test noise`
  - `--test sequence`
  - `--test chords`
  - `--test sweep`
- Debug/inspectie:
  - `--dump-regs`
  - `--counters`
  - `--debug` (rate-limited)

#### File playback (NUUT: v0.06 kandidaat)
- VGM file playback (SN76489 writes + delays)
- App-config base path vir VGM biblioteek
- CLI: spesifieke VGM file path speel onmiddellik

---

### 2.2 Out of scope (vir nou)
- VST/AU plugin (native DAW plugin)
- Cycle-perfect timing
- Effects (reverb/filter)
- Multi-file refactor (nog uitgestel)

---

## 3. Gebruikersverhaal (User Story)

> “Ek wil SN76489 as ’n engine hê wat eers in CLI tests stabiel is,  
> en dan kan uitbrei na file playback (VGM), en na DAW/MIDI gebruik as ’n virtuele instrument.”

---

## 4. Funksionele Vereistes

### 4.1 SN76489 Core
- Tone: 3 kanale, 10-bit period, 4-bit volume
- Noise: white/periodic, rate select, volume
- Register writes:
  - latch/data bytes
  - tone period updates
  - noise ctrl updates
  - volume updates
- Output:
  - mono PCM per chip

### 4.2 Multi-chip Engine
- Tot 128 onafhanklike chips
- Per chip: eie registers/state/counters
- Mixer: lineêr O(N)
- Per-chip gain + master gain

### 4.3 Stereo Routing
- Per chip of default global routing:
  - left / right / both
- Dual-mono (both) stuur selfde mono na L+R

### 4.4 Debug & Inspectie
- `--dump-regs` bly “golden output” format (stabiel vir regression)
- `--counters` toon per-chip en totaal stats

---

## 5. Test- en Run Modi (belangrik)

Die program moet verskillende run modes hê via CLI-argumente.

### 5.1 Beep Test
- `--test beep`
- Speel ’n vaste toon (bv. 440 Hz)
- Doel: audio path + tone register writes

### 5.2 Noise Test
- `--test noise`
- Toets white/periodic + rate/seed
- Doel: LFSR gedrag + determinisme

### 5.3 Mini Sequencer
- `--test sequence`
- Speel ’n vaste reeks note (bv. C–E–G–C)
- Doel: melodiese playback basis

### 5.4 Chords Test
- `--test chords`
- Speel 3 note gelyk (tone0/tone1/tone2)
- Doel: multi-channel mixing + clipping detection

### 5.5 Sweep Test
- `--test sweep`
- Pitch sweep (bv. 220→880 Hz)
- Doel: period write stabiliteit

---

## 6. Debug & Inspectie Modi

### 6.1 Register Dump
- CLI: `--dump-regs`
- Toon:
  - alle 8 SN76489 registers
  - latched register
  - afgeleide state (tone periods/freqs, volumes)
  - (v0.05+) voice allocation + envelope states

### 6.2 Debug Counters
- CLI: `--counters`
- Toon:
  - register writes
  - render calls
  - audio frames
  - MIDI events
  - envelope steps
  - (later) VGM commands processed + wait ticks

---

## 7. Kwaliteit-verbeterings

### 7.1 CLI: `--master-gain`
- Maklike volume trim sonder code edits
- Voorkom clipping by multi-channel/multi-chip

### 7.2 CLI: `--block-frames`
- Toets stutters vs latency
- Handig vir VGM playback later

### 7.3 “Golden” debug outputs
- `--dump-regs` output in vaste format (regression-friendly)

### 7.4 Seed control vir noise
- CLI: `--noise-seed 0x4000`
- Deterministiese tests

### 7.5 Noise rate control
- CLI: `--noise-rate {div16,div32,div64,tone2}`

---

## 8. Toekomstige Modules (later) — **verfyn**

### 8.1 MIDI-bestand Playback (later)
- Lees MIDI file met 1 instrument track
- Note on/off → SN76489 register writes
- File-based playback (nie realtime)
- Doel: reproduseer eenvoudige melodieë vanuit MIDI files

### 8.2 VGM Playback (NUUT, v0.06 kandidaat)
Doel: speel bestaande retro game music (VGM) deur die SN76489 emulator.

Funksionele vereistes:
- Lees VGM file vanaf disk
- Ondersteun:
  - SN76489 write commands
  - wait/delay commands (timing)
- Playback loop:
  - parse command → apply register write(s) → render wagtyd → herhaal
- CLI ondersteuning:
  - `--vgm-path <absolute_or_relative_path>`
    - begin onmiddellik met afspeel
  - `--vgm-base-dir <path>`
    - default location (app config) waar VGM library woon

Default voorbeeld (app-config instelbaar):
- `/Volumes/data1/Yandex.Disk.localized/michiele/Arduino/PCB Ontwerp/KiCAD/github/SN76489-synth-midi/src/tmp/src/`

Belangrik:
- v0.06 timing mag “audio-rate accurate” wees (nie cycle-perfect nie)
- Debug counters moet VGM metrics toon (commands, waits)

### 8.3 SN76489 as DAW Instrument (verfyn MIDI gedeelte)
Doel: engine kan MIDI ontvang en speel sodat Ableton/Logic MIDI kan stuur na die engine.

Vereistes:
- MIDI input via CoreMIDI (MacOS)
- MIDI channel → chip mapping
- Minimum:
  - Note On/Off
  - Velocity → volume mapping
  - Pitch Bend (v0.05)
  - (opsioneel later) sustain pedal CC64

Uitdruklik nie:
- AU/VST plugin in hierdie fase
- Multi-thread timing correction

---

## 9. Github (NUUT)

### 9.1 README vir breë publiek
Die repo moet ’n README hê wat:
- verduidelik wat die projek is (SN76489 emulator / engine)
- hoe om te installeer (pip deps)
- hoe om tests te run (beep/noise/sequence/chords/sweep)
- hoe om MIDI te gebruik
- hoe VGM playback later gaan werk (roadmap)

### 9.2 Git commit comment in tegniese specs
Elke release moet ’n standaard commit message hê (in TS opgeneem).

Voorbeeld vir v0.05:
- `git commit -m "v0.05: polyphonic voices + ADSR-lite + pitch bend; add chords/sweep tests"`

Vir v0.06 (VGM fokus) sal ons later ’n soortgelyke “one-liner” definieer.

---

## 10. Aanvaaringskriteria (vir volgende iterasie — v0.06 fokus op VGM)

Sukses vir v0.06 as:
- `--vgm-path` speel ’n VGM file hoorbaar af
- `--vgm-base-dir` werk as default library location
- Debug counters toon VGM commands processed + waits
- Geen regressie: v0.05 tests werk nog

---

## Review / Vervolgkeuses

Kies een:

1) **FS verfyn**  
   → “FS pas aan: …”

2) **FS goedkeur**  
   → Ek skryf **Tegniese Spesifikasie (TS v1.5)** vir v0.06 (VGM playback + CLI + timing model + debug output + sanity checks)

3) Ná TS v1.5  
   → Ek vra of jy **code v0.06** wil genereer (nog steeds één Python-bestand)

---

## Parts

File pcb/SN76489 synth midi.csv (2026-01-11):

Reference | Value | Footprint | Datasheet | Qty | DNP | Exclude from BOM | Exclude from Board
C1 | 10µF | Capacitor_THT:C_Radial_D6.3mm_H5.0mm_P2.50mm | ~ | 1
D1 | LED | LED_THT:LED_D3.0mm | ~ | 1
J1 | AudioJack3 | Connector_Audio:Jack_3.5mm_CUI_SJ1-3515N_Horizontal | ~ | 1
J2 | SSD1306_I2C | Display:Adafruit_SSD1306 | ~ | 1
J4 | SN_AUDIO_DEBUG | Connector_PinHeader_2.00mm:PinHeader_1x02_P2.00mm_Vertical | ~ | 1
R1 | 1K | Resistor_THT:R_Axial_DIN0204_L3.6mm_D1.6mm_P7.62mm_Horizontal | ~ | 1
R2 | 10 | Resistor_THT:R_Axial_DIN0204_L3.6mm_D1.6mm_P7.62mm_Horizontal | ~ | 1
R3,R4,R5 | R1k | Resistor_THT:R_Axial_DIN0204_L3.6mm_D1.6mm_P7.62mm_Horizontal | ~ | 3
R6 | 100 | Resistor_THT:R_Axial_DIN0204_L3.6mm_D1.6mm_P7.62mm_Horizontal | ~ | 1
RV1 | R_10k | Resistor_THT:R_Axial_DIN0204_L3.6mm_D1.6mm_P7.62mm_Horizontal | ~ | 1
SW0,9,SW0,10 | SW_SPST | Button_Switch_THT:KSA_Tactile_SPST | ~ | 2
U2 | PCF8574AP-I2C | Package_DIP:DIP-16_W7.62mm | http://www.nxp.com/docs/en/data-sheet/PCF8574_PCF8574A.pdf | 1
U3 | LM386 | Package_DIP:DIP-8_W7.62mm_Socket | http://www.ti.com/lit/ds/symlink/lm386.pdf | 1
U4 | SN76489 | w_pth_circuits:dil_16-300_socket | https://map.grauw.nl/resources/sound/texas_instruments_sn76489an.pdf | 1
U5 | WEMOS_S2_mini | RF_Module:WEMOS_C3_mini | https://www.wemos.cc/en/latest/c3/c3_mini.html | 1

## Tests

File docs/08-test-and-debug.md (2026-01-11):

# Stap 8 – Test- en debug-strategie
DIY USB-MIDI PSG-synth (SN76489 + ESP32-C2)

Doel:
- Van “geen idee wat er mis is” naar **deterministisch debuggen**
- Elke keten (USB → I2C → PCF → SN → audio) afzonderlijk kunnen valideren
- Meetprocedures vastleggen met jouw apparatuur:
  - RIGOL DHO804 oscilloscoop
  - Aneng SZ02 multimeter
  - Riden RC6006 labvoeding (indien externe 5 V nodig)

Ontwerpregel:
> Als een stap faalt: ga niet verder. Fix eerst de vorige meetpunt-fase.

---

## 0. Debug-setup (altijd eerst)

### 0.1 Hardware-opstelling
- Tablet links (Stap 4 + blokdiagram)
- Breadboard midden
- Scope + multimeter rechts

### 0.2 Scope basisinstellingen (startpunt)
- Probe: 10×
- Bandwidth limit: aan (als je HF-ruis wil onderdrukken), anders uit voor oscillatie-detectie
- Coupling:
  - Digitaal: DC
  - Audio: AC (voor snelle sanity checks)
- Ground clip: zo kort mogelijk (liefst spring ground)

### 0.3 Multimeter checks vóór power-on
- Continuity: geen kortsluiting tussen +5 V en GND
- I2C lijnen niet hard aan GND of +5V (controle weerstand)

---

## 1. Fase MP0 – USB MIDI enumeratie

### Doel
ESP32-C2 verschijnt als USB device (later: MIDI).

### Test
- Sluit aan op host
- Controleer:
  - CircuitPython drive zichtbaar
  - Serial console werkt

### Pass criteria
- Device boot zonder reset-loop
- Serial output toont “BOOT/READY”

### Fail patterns
- Reset-loop → te hoge load op 3.3 V / verkeerde wiring
- Geen serial → USB/board issue of firmware corrupt

---

## 2. Fase MP1 – I2C-bus gezondheid (OLED + PCF)

### Doel
I2C scan ziet devices (PCF + OLED).

### Test (skeleton)
- `system/diagnostics.i2c_scan()`
- Verwachting: adressen zoals `0x20` (PCF), `0x3C` (OLED) mogelijk

### Pass criteria
- Scan consistent (zelfde addresses bij elke reboot)

### Fail patterns + acties
- Scan leeg:
  - check SDA/SCL pins
  - check pull-ups (4.7–10 kΩ naar +5 V_DIG)
  - check GND shared (star-point)
- Alleen OLED, geen PCF:
  - PCF adres jumper/pin fout
  - PCF verkeerd om / geen 5 V
- Flaky scan (soms wel soms niet):
  - draden te lang
  - slechte breadboard contact
  - pullups te zwak/sterk → probeer 4.7 kΩ

---

## 3. Fase MP2 – PCF8574 data toggling

### Doel
PCF outputs veranderen betrouwbaar (D0..D7).

### Test (skeleton)
- `TEST_MODE = "pcf_counter"`
- Scope op:
  - D0 (moet snel togglen)
  - D7 of andere bit (ook toggles)

### Pass criteria
- Strakke digitale blokgolven
- Geen “half levels” of zwevende lijnen

### Fail patterns + acties
- Lijnen blijven hoog/laag:
  - verkeerde PCF pin mapping
  - PCF niet powered
  - I2C writes falen (terug naar MP1)
- Rare rimpel/instabiel:
  - ground clip te lang
  - breadboard contact slecht

---

## 4. Fase MP3 – Strobe/WE pulses naar SN76489

### Doel
Write-strobe pulses zichtbaar en op juiste polariteit.

### Test
- Gebruik `sn_beep` of een simpele write-loop
- Scope op strobe-lijn (PCF bit die jij gekozen hebt)

### Pass criteria
- Duidelijke pulses bij elke `write_byte()`
- Polariteit klopt:
  - active-low: korte LOW pulse
  - active-high: korte HIGH pulse

### Fail patterns + acties
- Geen pulses:
  - strobe bit in config fout (`PCF_STROBE_BIT`)
  - strobe wired naar verkeerde SN pin
- Puls is omgekeerd:
  - `STROBE_ACTIVE_LOW` verkeerd

---

## 5. Fase MP4 – SN76489 audio out (raw)

### Doel
PSG produceert toon/noise.

### Test
- Scope AC-coupled op SN audio out
- Verwachting:
  - klein AC signaal (tientallen tot honderden mVpp)

### Pass criteria
- Toon zichtbaar én verandert bij writes
- Geen grote DC-offset naar buiten toe (AC-coupling gebruik je later)

### Fail patterns + acties
- Flatline:
  - SN krijgt geen writes → terug naar MP2/MP3
  - SN clock ontbreekt (als jouw variant externe clock nodig heeft)
  - SN voeding/decoupling fout
- Heel veel HF-rommel:
  - grounding fout
  - te lange audio-draad
  - ontbrekende decoupling bij SN

---

## 6. Fase MP5 – Potmeter werking (wiper)

### Doel
Amplitude moet netjes mee veranderen.

### Test
- Scope op wiper van pot
- Draai pot van min → max

### Pass criteria
- Signaal amplitude verandert vloeiend
- Min stand: bijna nul

### Fail patterns + acties
- Geen verandering:
  - pot verkeerd aangesloten (wiper verwisseld)
  - signaal niet door pot maar omheen

---

## 7. Fase MP6 – Headphone out L/R dual-mono

### Doel
Tip en ring zijn identiek (dual-mono), geen DC op uitgang.

### Test
- Scope op tip en ring (AC coupled)
- Vergelijk amplitude en fase
- Multimeter DC meting op tip/ring t.o.v. sleeve:
  - moet ~0 V zijn (door C_out)

### Pass criteria
- L = R (zelfde golf)
- DC ~0 V

### Fail patterns + acties
- DC aanwezig:
  - C_out ontbreekt of verkeerd gepolariseerd
- Eén kanaal dood:
  - wiring jack fout
  - serie-R of C_out onderbroken

---

## 8. Audio kwaliteit debug (ruis, brom, piep)

### 8.1 Brom (50 Hz / 100 Hz)
Oorzaken:
- ground loop
- voeding ripple
Acties:
- star-ground check
- extra bulk cap bij audio sectie
- audio ground apart houden

### 8.2 Digitale piep (I2C/clock bleed)
Oorzaken:
- audio draden dicht langs SDA/SCL
- ground shared returns
Acties:
- fysiek scheiden (Stap 4 zones)
- kortere audio input
- Vref en opamp decoupling verbeteren (Optie B)

### 8.3 Oscillatie (hiss, ultrasonisch, warmte)
Oorzaken:
- output capacitieve load
- geen serie-R
Acties:
- R_out (47 Ω) per kanaal
- scope bandwidth open om “haar” te zien

---

## 9. Debug logging (firmware)

### Richtlijn
- Debug prints alleen op state-changes (niet elke sample)
- OLED updates max ~10 Hz

Aanbevolen logging regels:
- BOOT
- I2C scan result
- PCF init OK
- SN init OK
- TEST MODE actief

---

## 10. “Als X, check Y” cheat-sheet

- **Geen I2C scan** → check pullups, SDA/SCL, GND
- **PCF toggles niet** → terug naar I2C, check PCF addr
- **Strobe ontbreekt** → check strobe bit/polariteit
- **Wel strobe, geen audio** → check SN voeding/clock/audio pin
- **Audio ok, volume doet niks** → pot wiring
- **Audio ok, ruis/brom** → grounding + decoupling + routing (Stap 4)

---

## 11. Succescriteria Stap 8

Stap 8 is geslaagd als:
- Jij elke fout kunt herleiden tot één blok
- Je meetpunten MP0–MP6 kunt afvinken
- Je “random proberen” niet meer nodig hebt

---

## Volgende stap
**Stap 9 – Verbeter-voorstellen + vervolgvragen**

- Wat kan beter na eerste metingen?
- Wat verdient PCB-optimalisatie?
- Welke audio-optie wordt definitief?

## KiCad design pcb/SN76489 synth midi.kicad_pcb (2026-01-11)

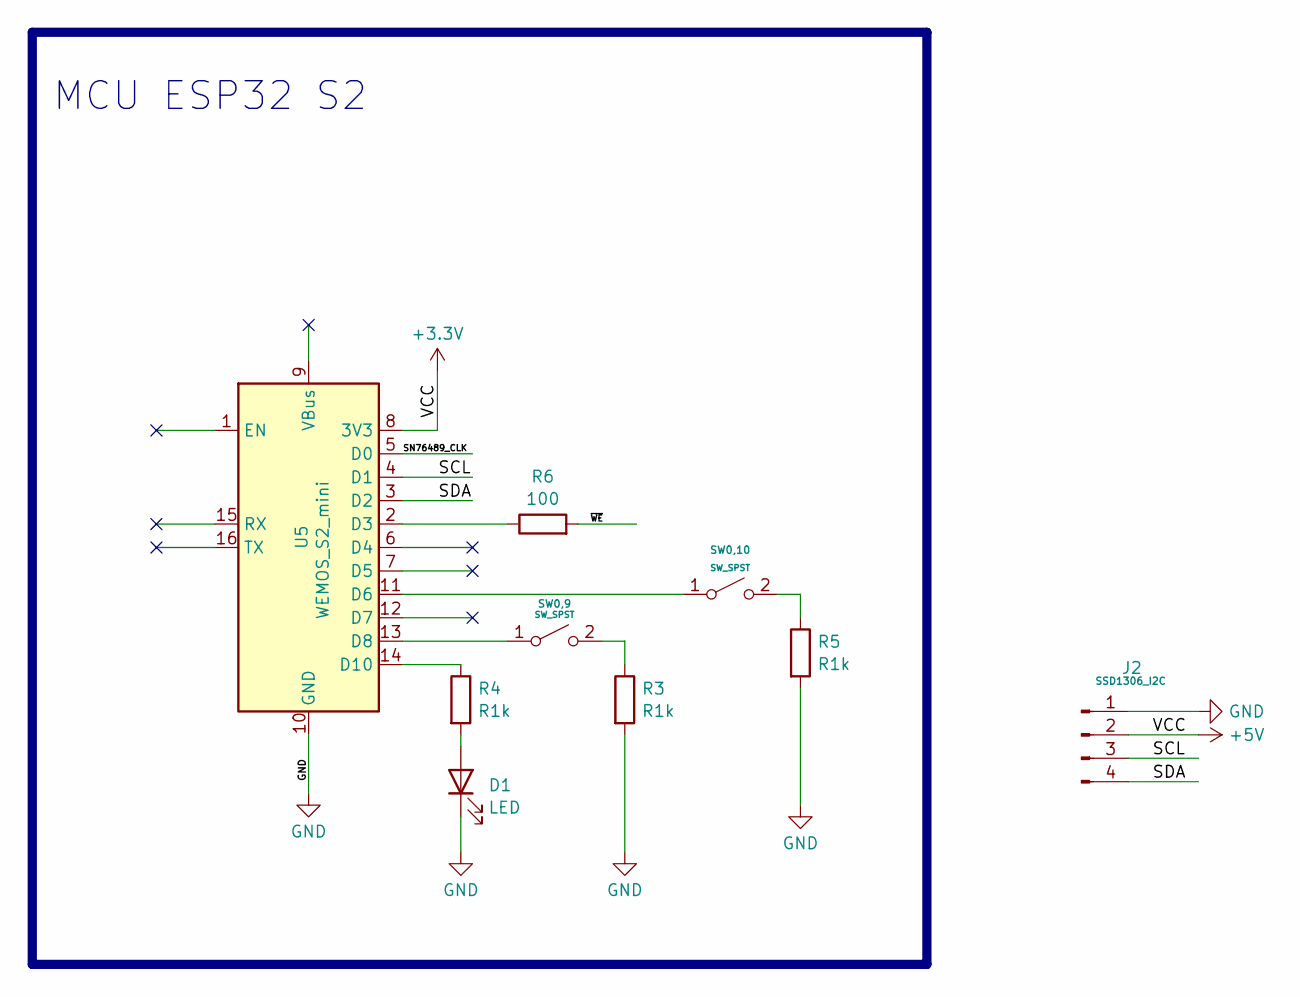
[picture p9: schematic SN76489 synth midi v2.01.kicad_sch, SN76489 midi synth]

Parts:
D1: LED; LED_D3.0mm
J2: SSD1306_I2C; Adafruit_SSD1306
R3, R4, R5: R1k; R_Axial_DIN0204_L3.6mm_D1.6mm_P7.62mm_Horizontal
R6: 100; R_Axial_DIN0204_L3.6mm_D1.6mm_P7.62mm_Horizontal
SW0,9, SW0,10: SW_SPST; KSA_Tactile_SPST
U5: WEMOS_S2_mini; WEMOS_C3_mini

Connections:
+3.3V: J2.2, U5.8 (3V3); also elsewhere on the board
/SCL: J2.3, U5.4 (D1); also elsewhere on the board
/SDA: J2.4, U5.3 (D2); also elsewhere on the board
/SN76489_CLK: U5.5 (D0); also elsewhere on the board
/~WE: R6.2; also elsewhere on the board
GND: D1.1 (K), J2.1, R3.2, R5.2, U5.10 (GND); also elsewhere on the board
unnamed: D1.2 (A), R4.2
unnamed: SW0,9.1 (A), U5.13 (D8)
unnamed: R3.1, SW0,9.2 (B)
unnamed: SW0,10.1 (A), U5.11 (D6)
unnamed: R5.1, SW0,10.2 (B)
unnamed: R6.1, U5.2 (D3)
unnamed: R4.1, U5.14 (D10)

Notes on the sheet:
MCU ESP32 S2

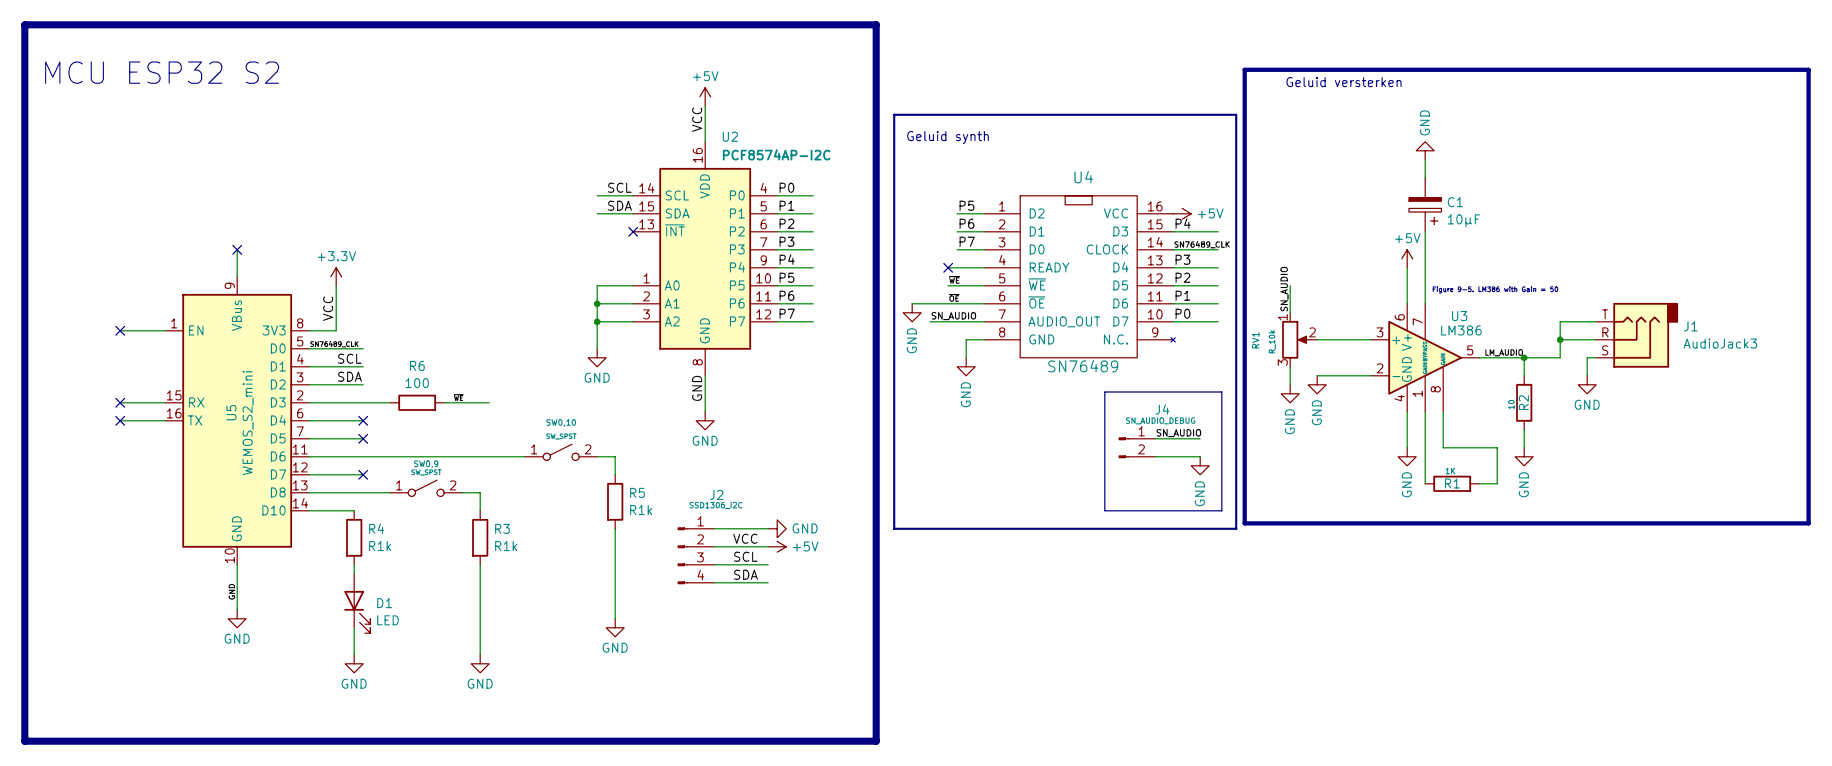
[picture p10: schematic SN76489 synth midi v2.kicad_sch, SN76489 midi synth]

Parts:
C1: 10µF; C_Radial_D6.3mm_H5.0mm_P2.50mm
D1: LED; LED_D3.0mm
J1: AudioJack3; Jack_3.5mm_CUI_SJ1-3515N_Horizontal
J2: SSD1306_I2C; Adafruit_SSD1306
J4: SN_AUDIO_DEBUG; PinHeader_1x02_P2.00mm_Vertical
R1: 1K; R_Axial_DIN0204_L3.6mm_D1.6mm_P7.62mm_Horizontal
R2: 10; R_Axial_DIN0204_L3.6mm_D1.6mm_P7.62mm_Horizontal
R3, R4, R5: R1k; R_Axial_DIN0204_L3.6mm_D1.6mm_P7.62mm_Horizontal
R6: 100; R_Axial_DIN0204_L3.6mm_D1.6mm_P7.62mm_Horizontal
RV1: R_10k; R_Axial_DIN0204_L3.6mm_D1.6mm_P7.62mm_Horizontal
SW0,9, SW0,10: SW_SPST; KSA_Tactile_SPST
U2: PCF8574AP-I2C; DIP-16_W7.62mm
U3: LM386; DIP-8_W7.62mm
U4: SN76489; DIP-16_W7.62mm
U5: WEMOS_S2_mini; WEMOS_C3_mini

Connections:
+3.3V: J2.2, U2.16 (VDD), U3.6 (V+), U4.16 (VCC), U5.8 (3V3)
/LM_AUDIO: J1.R, J1.T, R2.2, U3.5
/P0: U2.4 (P0), U4.10 (D7)
/P1: U2.5 (P1), U4.11 (D6)
/P2: U2.6 (P2), U4.12 (D5)
/P3: U2.7 (P3), U4.13 (D4)
/P4: U2.9 (P4), U4.15 (D3)
/P5: U2.10 (P5), U4.1 (D2)
/P6: U2.11 (P6), U4.2 (D1)
/P7: U2.12 (P7), U4.3 (D0)
/SCL: J2.3, U2.14 (SCL), U5.4 (D1)
/SDA: J2.4, U2.15 (SDA), U5.3 (D2)
/SN76489_CLK: U4.14 (CLOCK), U5.5 (D0)
/SN_AUDIO: J4.1, RV1.1, U4.7 (AUDIO_OUT)
/~WE: R6.2, U4.5 (~WE)
GND: C1.2, D1.1 (K), J1.S, J2.1, J4.2, R2.1, R3.2, R5.2, RV1.3, U2.1 (A0), U2.2 (A1), U2.3 (A2), U2.8 (GND), U3.2 (-), U3.4 (GND), U4.6 (~OE), U4.8 (GND), U5.10 (GND)
unnamed: D1.2 (A), R4.2
unnamed: R1.1, U3.1 (GAIN)
unnamed: R1.2, U3.8 (GAIN)
unnamed: SW0,9.1 (A), U5.13 (D8)
unnamed: R3.1, SW0,9.2 (B)
unnamed: SW0,10.1 (A), U5.11 (D6)
unnamed: R5.1, SW0,10.2 (B)
unnamed: RV1.2, U3.3 (+)
unnamed: C1.1, U3.7 (BYPASS)
unnamed: R6.1, U5.2 (D3)
unnamed: R4.1, U5.14 (D10)

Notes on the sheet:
Geluid versterken
Figure 9-5. LM386 with Gain = 50
MCU ESP32 S2
Geluid synth

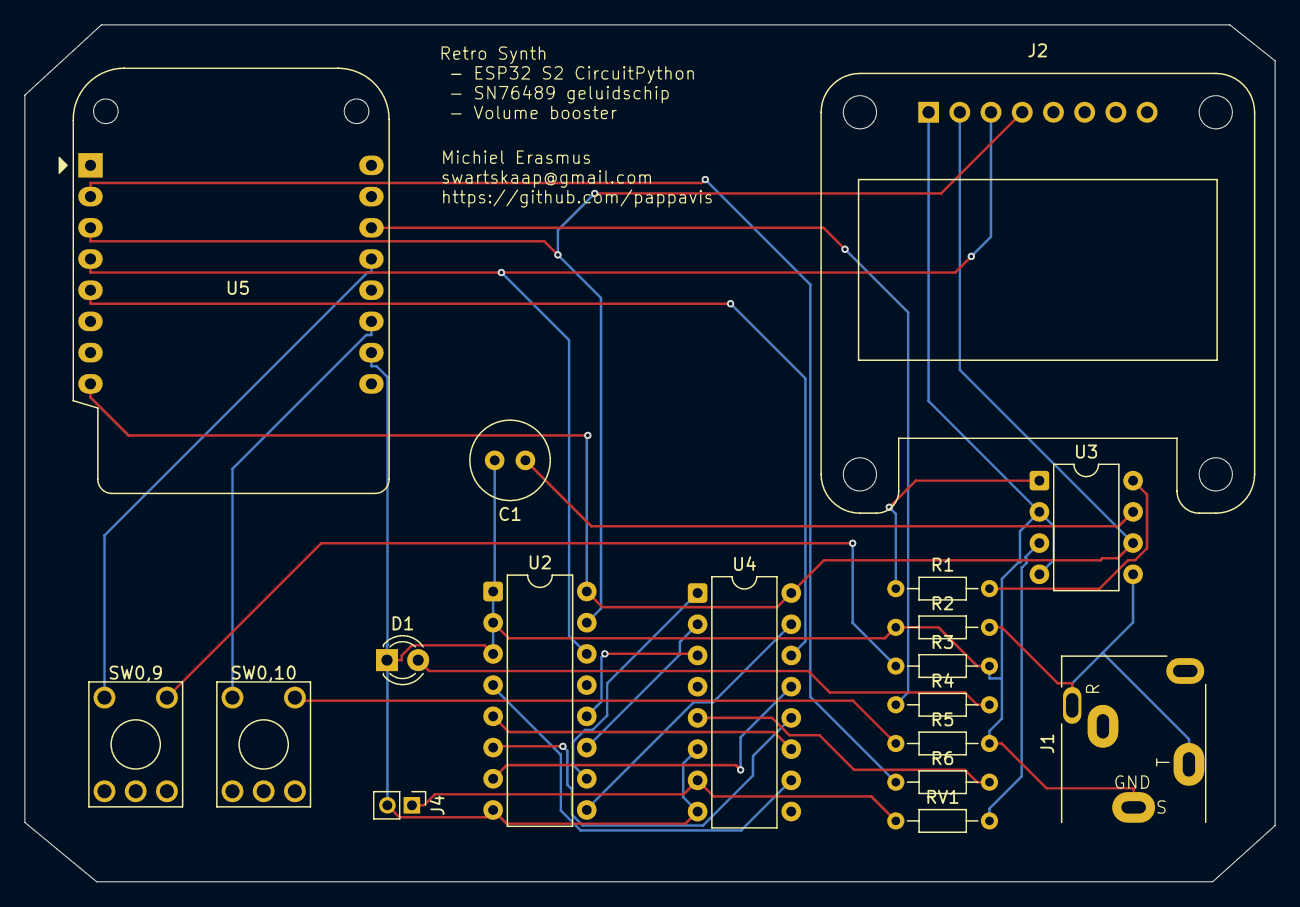
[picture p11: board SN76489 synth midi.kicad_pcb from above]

Board: 2 copper layers, 101.7 x 69.7 mm, 18 parts (0 on the bottom side), 27 nets.

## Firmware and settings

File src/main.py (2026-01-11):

# main.py
import time
import board
import busio

from system import config
from system.diagnostics import i2c_scan, pcf_counter_test, sn_beep_test
from drivers.pcf8574 import PCF8574
from drivers.sn76489 import SN76489
from drivers.oled_status import OLEDStatus

def log(*args):
    if config.DEBUG:
        print(*args)

def init_i2c():
    i2c = busio.I2C(board.SCL, board.SDA, frequency=config.I2C_FREQ)
    # Wait for I2C to become ready
    t0 = time.monotonic()
    while not i2c.try_lock():
        if time.monotonic() - t0 > 2:
            break
    try:
        # quick unlock if we locked
        if i2c.try_lock():
            i2c.unlock()
    except Exception:
        pass
    return i2c

def main():
    log("BOOT")
    i2c = init_i2c()

    # OLED is optional; it must never block the system
    oled = OLEDStatus(i2c, address=config.OLED_ADDR, debug=config.DEBUG)
    oled.splash("BOOT")

    addrs = i2c_scan(i2c, debug=config.DEBUG)
    oled.show_lines(["I2C scan OK", " ".join([hex(a) for a in addrs[:4]])])

    # PCF8574 (required for SN76489 writes)
    pcf = PCF8574(
        i2c,
        address=config.PCF_ADDR,
        strobe_bit=config.PCF_STROBE_BIT,
        active_low=config.STROBE_ACTIVE_LOW,
        data_settle_us=config.DATA_SETTLE_US,
        strobe_pulse_us=config.STROBE_PULSE_US,
        post_write_us=config.POST_WRITE_US,
        debug=config.DEBUG
    )

    # SN76489 driver (bridged via PCF)
    sn = SN76489(pcf, debug=config.DEBUG)
    sn.mute_all()

    # Test modes for bring-up
    if config.TEST_MODE == "pcf_counter":
        log("Running PCF counter test (MP2)")
        pcf_counter_test(pcf, oled=oled, debug=config.DEBUG, delay_ms=50)
    elif config.TEST_MODE == "sn_beep":
        log("Running SN beep test (MP3/MP4)")
        sn_beep_test(sn, oled=oled, debug=config.DEBUG)
    else:
        oled.show_lines(["READY", "Waiting MIDI..."])
        log("READY (no MIDI implemented in this skeleton)")
        while True:
            time.sleep(0.5)

if __name__ == "__main__":
    main()

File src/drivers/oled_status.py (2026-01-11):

# drivers/oled_status.py
# Minimal OLED status wrapper. Safe fallback if OLED lib is unavailable.
import time

class OLEDStatus:
    def __init__(self, i2c, address=0x3C, debug=False):
        self.i2c = i2c
        self.address = address
        self.debug = debug
        self._ready = False
        self._init_display()

    def _init_display(self):
        try:
            import adafruit_ssd1306
            self.display = adafruit_ssd1306.SSD1306_I2C(128, 64, self.i2c, addr=self.address)
            self.display.fill(0)
            self.display.show()
            self._ready = True
        except Exception as e:
            self._ready = False
            self.display = None
            if self.debug:
                print("OLED disabled:", e)

    @property
    def ready(self):
        return self._ready

    def show_lines(self, lines):
        """Display up to ~6 lines. If OLED not present, just prints."""
        if not isinstance(lines, (list, tuple)):
            lines = [str(lines)]
        if not self._ready:
            if self.debug:
                print("OLED:", " | ".join(lines))
            return
        try:
            import terminalio
            from adafruit_display_text import label
            from adafruit_display_text import wrap_text_to_lines

            self.display.fill(0)
            y = 0
            for line in lines[:6]:
                text_area = label.Label(terminalio.FONT, text=str(line), x=0, y=y+8, color=1)
                self.display.show(text_area)
                y += 10
            self.display.show()
        except Exception as e:
            if self.debug:
                print("OLED draw error:", e)

    def splash(self, title="BOOT", delay_s=0.2):
        self.show_lines([title])
        time.sleep(delay_s)

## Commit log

2026-01-11 0.01 UNTESTED version.. need to breadboard it
    [SN76489 synth midi 01.kicad_pcb, SN76489 synth midi.csv, SN76489 synth midi.dsn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]
2026-01-18 0.01 PCB versie
    [SN76489 synth midi-B_Cu.gbr, SN76489 synth midi-B_Mask.gbr, SN76489 synth midi-B_Paste.gbr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]
2026-02-02 v0.05: add 3-voice allocation per chip, ADSR-lite via volume writes, pitch bend; new --test chords/--test sweep
    [SN76489 synth midi v2.01.kicad_sch, SN76489 synth midi v2.kicad_sch]
